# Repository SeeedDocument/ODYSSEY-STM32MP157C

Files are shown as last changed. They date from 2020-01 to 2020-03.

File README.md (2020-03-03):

---
name: ODYSSEY – STM32MP157C 
category: ODYSSEY
bzurl: https://www.seeedstudio.com/ODYSSEY-STM32MP157C-p-4464.html
wikiurl: http://wiki.seeedstudio.com/ODYSSEY-STM32MP157C/
sku: 102110319
---

# ODYSSEY – STM32MP157C

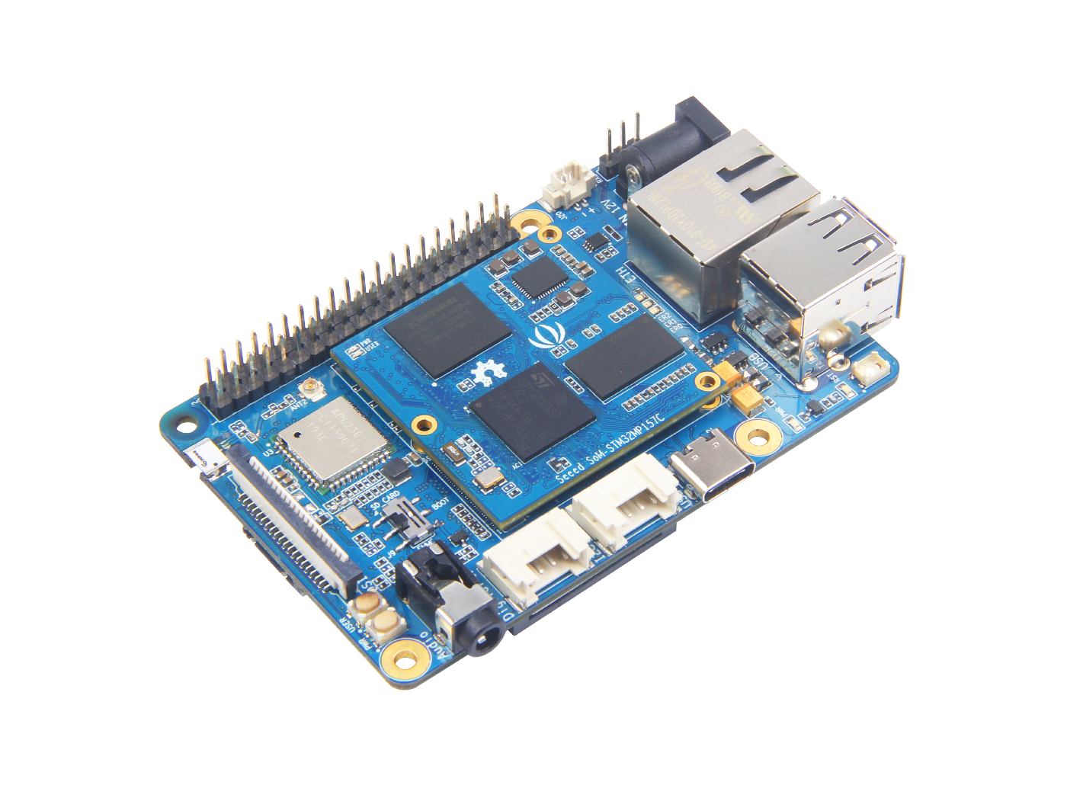
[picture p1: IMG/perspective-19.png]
 

The ODYSSEY – STM32MP157C is a single board computer that based on STM32MP157C, a dual-core Arm-Cortex-A7 core processor operating at 650Mhz. The processor also integrates an Arm Cortex-M4 coprocessor, which makes it suitable for real-time task. The ODYSSEY – STM32MP157C is created in a form of SoM(system on module) plus a Carrier board. The SoM has consisted of the MPU, PMIC, RAM and the carrier board is in Raspberry Pi form factor. The carries board includes all the necessary peripherals including Gigabytes Ethernet, WiFi/BLE, DC Power，USB Hosts, USB-C, MIPI-DSI, DVP for camera, audio, etc. With this board, customers can fast evaluate the SoM and deploy the SoM on their own carrier board easily and quickly.

Get one now (https://www.seeedstudio.com/ODYSSEY-STM32MP157C-p-4464.html)

## Features

- Dual-core Arm-Cortex-A7 core processor with Cortex-M4 integrated
- SoM(system on module) includes MPU, PMIC, RAM. 
- Raspberry Pi 40-Pin Compatible Carrier Board.
- Compact size and powerful
- open source hardware/SDK/API/BSP/OS

## Specification

|Item|Values|
|----|---|
|Peripheral Interface| 2 x USB Host<br>1 x gigabit Ethernet interface<br>1 x 3.5mm audio interface<br>1 x MIPI DSI display interface<br>1 x DVP camera interface<br>2 x Grove (GPIO & I2C)<br>1 x SD card interface (on the back of the board)|
|WiFi/Bluetooth|WiFi 802.11 b/g/n 2.4GHz<br>Bluetooth 4.1|
|On-board LED|1 x reset LED<br>3 x user-defined LED<br>1 x power LED|
|Power|1 x DC interface (12V/2A power input is recommended)<br>1 x USB Type - C|
|Button|1 x reset button<br>1 x user button<br>1 x dial code key|
|dimension|56mm x 85mm|
|Operating temperature | 0 ~ 75 ℃ |

## Application

- Industrial (CAN-Ethernet gateways etc )
- White goods(refrigerators,microwaves etc )
- Medical(data loggers etc)
- High-end wearables(VR device etc)
- Smart Home Devices

## Hardware Overview

<iframe src="https://3dwarehouse.sketchup.com/embed/6eecf961-5dd1-4baf-94e4-72f130c5542d" frameborder="0" scrolling="no" marginheight="0" marginwidth="0" width="580" height="326" allowfullscreen></iframe>

ODYSSEY – STM32MP157C consists of two parts: Carrier board and Seeed SoM - STM32MP157C.

Carrier board hardware details follow:

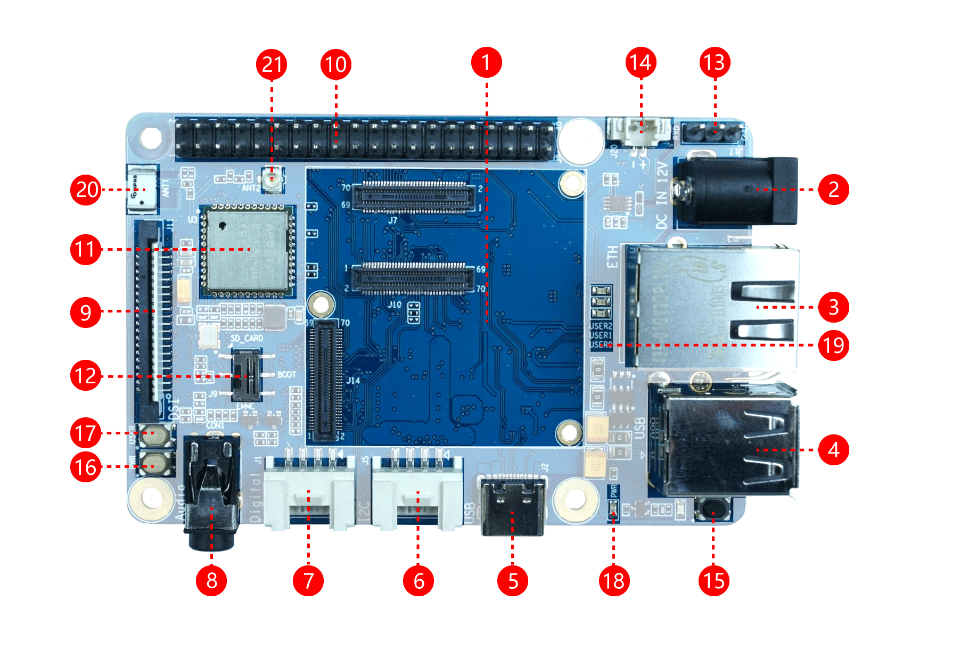
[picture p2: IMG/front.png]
 

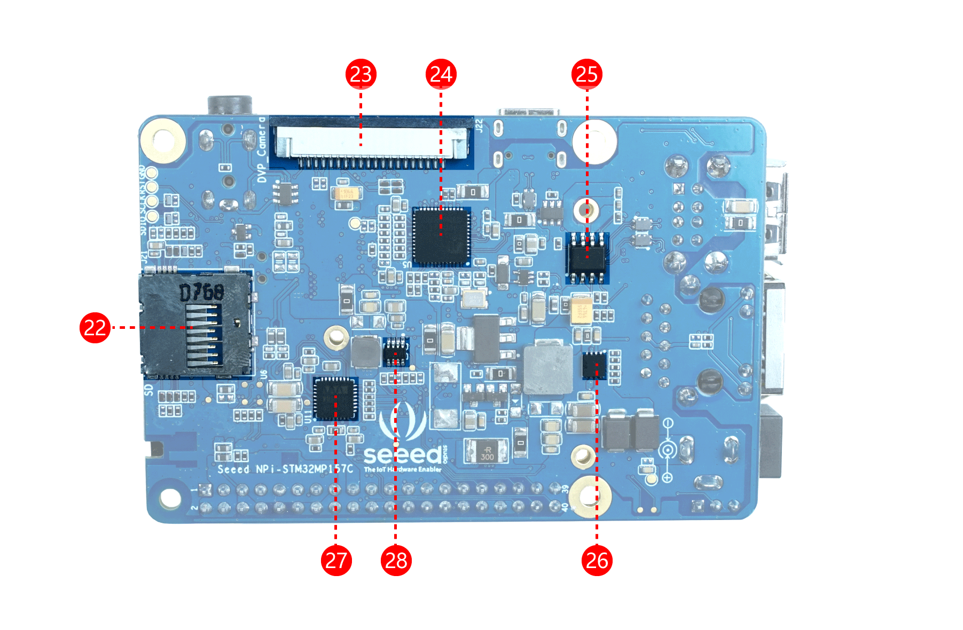
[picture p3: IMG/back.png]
 

- **1.Carrier board :** Install the Seeed SoM-STM32MP157C area, if the user wants to remove the core board, slowly tilt the core board up and then remove, never remove by hand.

- **2.DC Power Input Port :** 12V~24V/2A (12V/2A power input is recommended).

- **3.ETH Interface :** Network cable interface can be connected to gigabit level network.

- **4.USB Host:** Two USB Host ports.

- **5.USB Device:** USB 2.0 Type C. If Type C is used as board power input, a 5V/3A power adapter should be used.

- **6.Digital Grove Interface:** Connect the Grove interface to the digital pin. 

- **7.IIC Grove Interface:** Connect the Grove interface to the IIC pin.

- **8.American Standard 3.5mm:**  Audio interface.

- **9.MIPI DSI Interface:** Connect to a display with a MIPI DSI interface(FPC 20Pin 1.0mm).

- **10.40 PIN GPIO Interface:** Compatible with Raspberry Pi's 40-PIN.

- **11.AP6236:** 2.4G WiFi & BT 4.2 control chip.

- **12.Slide Switch:** Can be used to select SD card or eMMC to start.

- **13.Debug UART:** The system default debugging serial port can enter this serial port to access the system, we'll talk more about how to do that later.

- **14.JST 1.0mm:** 3VRTC battery interface.

- **15.RST Key:** system reset key.

- **16.PWR Button:** Long press about 8S to shut down, short press to boot.

- **17.User Button:** User programmable buttons.

- **18.PWR LED:** Development board power led.

- **19.User LED:** User programmable led.

- **20.ACA-5036-A2-CC-S:** Onboard 2.4G ceramic antenna.

- **21.The IPEX 1 generation:** External 2.4 G external antenna seat(When using an external antenna, need remove R49, R51 0Ω welding)

- **22. SD card slot:** Is the area where a micro-sd card with the system is inserted.

- **23.DVP camera interface :** Connect to camera with DVP interface (FPC 20Pin 1.0mm).

- **24.KSZ9031:** 1000M Network cable drive network card.

- **25.STMPS2252MTR:** Power switch chip.

- **26.MP9943:** Buck DCDC Power chip.

- **27.WM8960:** Audio codec chip.

- **28.MP2161:** Buck DCDC Power chip.

### Pin Function

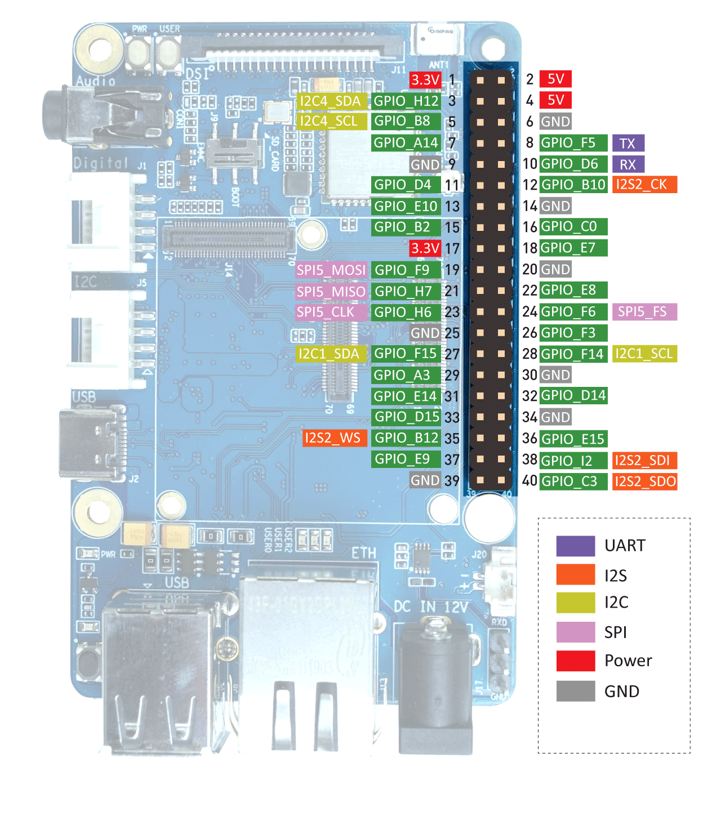
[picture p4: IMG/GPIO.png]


ODYSSEY - STM32MP157C's 40-pin is fully compatible with Raspberry Pi's 40PIN, including GPIO, IIC, UART, SPI, IIS and PWM pins.

## Introduction To Software

### Preparatory Work

**Materials Required**

- ODYSSEY – STM32MP157C
- Wi-Fi network
- 4GB (or more memory) SD card and SD card reader
- PC or Mac
- [USB To Uart Adapter](https://www.seeedstudio.com/USB-To-Uart-5V%26amp%3B3V3-p-1832.html) (optional)
- 12V/2A DC interface adapter for power supply (optional)
- A USB type-c cable

<div class="admonition warning">
<p class="admonition-title">Caution</p>
Please plug the USB cable gently, otherwise you may damage the interface.Please use the USB cable with 4 wires inside, the 2 wires cable can't transfer data. If you are not sure about the wire you have, you can click <a href="https://www.seeedstudio.com/USB-3-1-Type-C-to-A-Cable-1-Meter-3-1A-p-4085.html"><B>here</B></a> to buy
</div>

**Mirror Installation**

Like Raspberry Pi, you need to install the ODYSSEY – STM32MP157C image from your SD card to get it up and running. We offer two ways to start ODYSSEY – STM32MP157C. You can boot from an SD card or from eMMC.

**A. Boot from SD card**

- **Step 1.** Select the [firmware](https://github.com/Seeed-Studio/seeed-linux-images) you want to download:

- **Step 2.** Connect an SD card to a PC or MAC with an SD card reader, an SD card with more than 4G memory is required.

- **Step 3.** <font face="">Click here to download <a href="https://etcher.io/">Etcher</a>, then use the Etcher to write the  ```*.img.xz``` file directly to the SD card. Or extract the ```*.img.xz``` file into a ```*.img``` file, and then burn it to an SD card using another mirror write tool. 
<br>
<br>Click the plus icon to add the newly downloaded image file and the software will automatically select the SD card you inserted. Then click Flash! writing. It takes about 10 minutes to finish.</font>



- **Step 4.** After writing the image to the SD card, insert the SD card into ODYSSEY – STM32MP157C. Use USB type-c port to power the Carrier board. Do not take out the SD card during writing. ODYSSEY – STM32MP157C will boot from the SD card, you can see the PWR and USER LED lighting on SOM. Now, go to the next section: the serial console.

<div class="admonition note" >
<p class="admonition-title">Note</p>
they mean to start up failed if the USER LED does not blink.Please check the boot switch whether it is SD_CARD.
</div>

**B. Boot from eMMC card**

- **Step 1.** the process is the same as **A. Boot from SD card** if you first start up the ODYSSEY – STM32MP157C.

- **Step 2.** Edit /boot/uEnv.txt to start eMMC boot then reboot.

```bash
sudo echo cmdline=init=/opt/scripts/tools/eMMC/init-eMMC-flasher-v3-stm32mp1.sh >> /boot/uEnv.txt
sudo reboot
```

- **Step 3.** Wait for the USER LED bright continuously.that indicate the eMMC boot successfully if the USER LED bright continuously.

- **Step 4.** Power off and unplug the SD card.

- **Step 5.** Set the slide switch to EMMC and restart.

**Serial Console**

Now your ODYSSEY – STM32MP157C is up, you may want to access your Linux system through the console, then set up WiFi, and so on. Two serial port access methods are provided for Linux access: 

- A. OTG USB port - You need to run a Linux system on a circuit board.

- B. UART port - Used to debug low-level problems.

**A. Connect via OTG**

- **Step 1.** Take a USB type-c cable and make sure it's a data cable, plug it into ODYSSEY – STM32MP157C's USB type-c port, and then plug the other end of the USB type-c cable into your computer. 

- **Step 2.** Check whether the computer serial port is enabled:

    - Windows : Check the device manager, there should be a new serial device named ```COMx```, x is a bigger and bigger number. If you can not recognizes the driver you can visit [link](https://beagleboard.org/getting-started#troubleshooting) to install the driver.
    - Linux : ls ```/dev/ttyACM*```, should be ```/dev/ttyACMx``` x depends on the USB port you use.
    - Mac : ls ```/dev/cu.usb*```, should be ```/dev/cu.usbmodem14xx``` xx depends on the USB port you use.

- **Step 3.** Use your favorite serial debugging tool to connect to serial ports: 115200 baud rate, 8 bits, no parity bits, a stop bit 1, no flow control. Here are SoMe examples:

    - Windows : Use [PUTTY](https://www.chiark.greenend.org.uk/~sgtatham/putty/latest.html), select ```Serial``` protocol, fill in the COM port corresponding to ODYSSEY -STM32MP157C,```115200``` baud rate, 8 bit, no parity bits, a stop bit 1, no flow control.
    - Linux : Depending on the USB To TTL Adapter, should be ```screen /dev/ttyACM0(,1, and so on) 115200``` or ```screen /dev/ttyUSB0(,1, and so on) 115200```.
    - Mac : Depending on the USB To TTL Adapter, should be ```screen /dev/cu.usbserial1412(,1422, and so on) 115200``` or ```screen /dev/cu.usbmodem1412(,1422, and so on) 115200```.

- **Step 4.** The default user name is ```debian```, the password is ```temppwd```.

**B. Connect via UART port**

In this section, we'll walk you through the use of the USB to TTL adapter, which connects to the ODYSSEY – STM32MP157C's Uart port(Located at the upper right of ODYSSEY – STM32MP157C), to establish a connection between your computer and ODYSSEY -STM32MP157C.

- **Step 1.** Connect Uart port To PC/Mac using USB To TTL Adapter.If you don't have USB To TTL Adapter, click [HERE](https://www.seeedstudio.com/catalogsearch/result/?q=UART) to buy.（RX->TX,TX->RX）

- **Step 2.** Using the following serial debugging tools, the baud rate is 115200:
    - Windows : Use [PUTTY](https://www.chiark.greenend.org.uk/~sgtatham/putty/latest.html), select ```Serial``` protocol, fill in the COM port corresponding to ODYSSEY -STM32MP157C,```115200``` baud rate, 8 bit, no parity bits, a stop bit 1, no flow control.
    - Linux : Depending on the USB To TTL Adapter, should be ```screen /dev/ttyACM0(,1, and so on) 115200``` or ```screen /dev/ttyUSB0(,1, and so on) 115200```.
    - Mac : Depending on the USB To TTL Adapter, should be ```screen /dev/cu.usbserial1412(,1422, and so on) 115200``` or ```screen /dev/cu.usbmodem1412(,1422, and so on) 115200```.

- **Step 3.** The default user name is ```debian```, the password is ```temppwd```

- **Step 4.** If you don't have USB to TTL Adapter, you can also use Arduino. If you use Arduino, connect one end of the jumper to the Arduino's RESET pin and the other end to the Arduino's GND pin. This will bypass your Arduino's ATMEGA MCU and turn your Arduino into a USB to TTL adapter. Please refer [HERE](https://www.youtube.com/watch?v=qqSLwK1DP8Q) Video tutorial. Now connect the GND pin of Arduino to the GND pin of ODYSSEY -STM32MP157C's Uart port. Connect Rx pins on Arduino to Rx pins on ODYSSEY -STM32MP157C's Uart port. Connect the Tx pin on the Arduino to the Tx pin on the ODYSSEY -STM32MP157C Uart port. Finally, connect the Arduino to the PC/Mac via the Arduino's USB cable. Now check to see if your PC/Mac has found your Arduino by typing the following command:

```
ls /dev/cu.usb* (Mac)
ls /dev/ttyACM* (Linux)
```
You should get feedback like this:

```
/dev/cu.usbmodem14XX where XX will vary depending on which USB port you used (on Mac)
/dev/ttyACMX where X will vary depending on which USB port you used  (on Linux)
```
Now follow the steps above to connect to ODYSSEY – STM32MP157C via a serial connection. This is usually what we need to do when we first boot up, as you will then set up ODYSSEY – STM32MP157C for Wi-Fi connection and then SSH connection.

**Network Settings**

**A. Wi-Fi Settings**

Configure the ODYSSEY – STM32MP157C network through the network management tool `connmanctl`, which has been installed on the ODYSSEY -STM32MP157C image. Follow these instructions to easily complete the configuration. 

```
robot@ev3dev:~$ sudo connmanctl
Error getting VPN connections: The name net.connman.vpn was not provided by any
connmanctl> enable wifi
Enabled wifi
connmanctl> scan wifi
Scan completed for wifi
connmanctl> services
*AO Wired                ethernet_b827ebbde13c_cable
                         wifi_e8de27077de3_hidden_managed_none
    AH04044914           wifi_e8de27077de3_41483034303434393134_managed_psk
    Frissie              wifi_e8de27077de3_46726973736965_managed_psk
    ruijgt gast          wifi_e8de27077de3_7275696a67742067617374_managed_psk
    schuur               wifi_e8de27077de3_736368757572_managed_psk
connmanctl> agent on
Agent registered
connmanctl> connect wifi_e8de27077de3_41      # You can use the TAB key at this point to autocomplete the name
connmanctl> connect wifi_e8de27077de3_41483034303434393134_managed_psk
Agent RequestInput wifi_e8de27077de3_41483034303434393134_managed_psk
  Passphrase = [ Type=psk, Requirement=mandatory ]
Passphrase? *************
Connected wifi_e8de27077de3_41483034303434393134_managed_psk
connmanctl> quit
```

Now use the following command to find ODYSSEY – STM32MP157C's IP address. 
```
ifconfig
```

**B. Ethernet connection**

You can connect to the network using an Ethernet cable. Just plug in the Ethernet cable to the Internet.

**SSH connection**

**A. SSH**

SSH, short for Secure Shell, is formulated by the Network Working Group of IETF. SSH is a security protocol based on the application layer. SSH is a more reliable protocol that provides security for remote login sessions and other network services. There is no SSH protocol in the image provided by us, so we need to configure it through the serial port, so as to realize the communication between the device and the computer through SSH protocol. Enter the following command to install the SSH service in ODYSSEY -STM32MP157C.

```bash
sudo apt install ssh -y
```

Next, we'll use SSH to access ODYSSEY – STM32MP157C. Windows users can use third-party SSH clients. For Linux/Mac users, the SSH client is built in.

- Windows users : Use PUTTY, select SSH protocol, fill in the correct IP address and click open. The user name is debian and the password is temppwd.

- Linux/Mac users :
```
ssh debian@IP
// password: temppwd
```

<div class="admonition note" >
<p class="admonition-title">Note</p>
If the performance experience degrades while using SSH, please switch to a more accessible WiFi network.
</div>

## CANBUS Communication

The following is the process of CANBUS communication using [2 Channel CAN BUS FD Shield for Raspberry Pi](https://www.seeedstudio.com/2-Channel-CAN-BUS-FD-Shield-for-Raspberry-Pi-p-4072.html) based on ODYSSEY -- STM32MP157C, first use [Seeeduino V4.2](https://www.seeedstudio.com/Seeeduino-V4-2-p-2517.html) to collect the environment temperature and humidity, and then through the Seeeduino V4.2 [CAN - BUS shields V2](https://www.seeedstudio.com/CAN-BUS-Shield-V2.html) above and the ODYSSEY – STM32MP157C Channel 2 CAN BUS FD shields above for Raspberry Pi communication.

###Preparation Work

**Materials Required**

- ODYSSEY - STM32MP157C
- Wi-Fi network
- 4GB (or more than 4GB) SD card and SD card reader
- PC or Mac
- [USB To Uart Adapter](https://www.seeedstudio.com/USB-To-Uart-5V%26amp%3B3V3-p-1832.html)(optional)
- 12V/2ADC interface adapter for power supply (optional)
- A USB type-c cable
- Two double-male dupont lines
- [CAN-BUS Shield V2](https://www.seeedstudio.com/CAN-BUS-Shield-V2.html)
- [Seeeduino V4.2](https://www.seeedstudio.com/Seeeduino-V4-2-p-2517.html)
- [2 Channel CAN BUS FD Shield for Raspberry Pi](https://www.seeedstudio.com/2-Channel-CAN-BUS-FD-Shield-for-Raspberry-Pi-p-4072.html)
- [Grove - Light Sensor v1.2](https://www.seeedstudio.com/Grove-Light-Sensor-v1-2.html)
- [Grove - I2C High Accuracy Temp&Humi Sensor (SHT35)](https://www.seeedstudio.com/catalogsearch/result/?q=sht35)

**Hardware Connection**

- **Step 1.** According to the [installation guide](http://wiki.seeedstudio.com/2-Channel-CAN-BUS-FD-Shield-for-Raspberry-Pi/#mounting-guide) insert 2 Channel CAN BUS FD Shield for Raspberry Pi onto ODYSSEY - STM32MP157C.
- **Step 2.** Insert CAN BUS Shield V2 into Seeeduino V4.2.
- **Step 3.** Connect Channel CAN BUS FD Shield for Raspberry Pi to can-bus Shield V2 using dupont wire.

|2 Channel CAN BUS FD Shield for Raspberry Pi|CAN-BUS Shield V2|
|:----:|:---:|
|CAN_0_L|CANL|
|CAN_0_H|CANH|

- **Step 4.** Power ODYSSEY STM32MP157C and Seeeduino V4.2

**Dependency installation**

- **Step 1.** Install the environment for `python`.

```bsah
sudo apt update
sudo apt install python3 python3-distutils python3-pyqt5  python3-pip python3-numpy -y
sudo pip3 install python-can pyqtgraph
```
- **Step 2.** Install `git`.

```bsah
sudo apt install git -y
```

- **Step 3.** Install the `make` related environment.

```bsah
sudo apt install make device-tree-compiler gcc -y
```

### software installation

**Install CAN-HAT and LCD drivers**

- **Step 1.** Check the version of Linux kernel in the current environment and install the header file of kernel version.

```bash
dpkg -l | grep linux
sudo apt install linux-headers-$(uname -r) -y
```

- **Step 2.** Make and install driver of stm32p1 from `seeed-linux-dtverlays` in the GitHub.

```bash
git clone https://github.com/Seeed-Studio/seeed-linux-dtverlays
cd seeed-linux-dtverlays
make all_stm32mp1 && sudo make install_stm32mp1
```

- **Step 3.** add dtbo package in `/boot/uEnv.txt` to make it become effective after reboot.

```bash
sudo echo uboot_overlay_addr0=/lib/firmware/stm32mp1-seeed-lcd-01-overlay.dtbo >> /boot/uEnv.txt
sudo echo uboot_overlay_addr1=/lib/firmware/stm32mp1-MCP2517FD-can0-overlay.dtbo >> /boot/uEnv.txt
sudo reboot
```

- **Step 4.** Check the driver whether install successfully by using `dmesg`, you will view the below information if it is successful.

```bash
debian@npi:~$ sudo insmod /lib/modules/$(uname -r)/extra/seeed/mcp25xxfd-can.ko
debian@npi:~$ dmesg | grep spi
[    1.057609] spi_stm32 44009000.spi: driver initialized
[    9.852726] mcp25xxfd spi0.0: Linked as a consumer to regulator.6
[    9.966510] mcp25xxfd spi0.0: MCP2517 successfully initialized.

debian@npi:~$ ifconfig -a
can0: flags=128<NOARP>  mtu 16
        unspec 00-00-00-00-00-00-00-00-00-00-00-00-00-00-00-00  txqueuelen 10  (UNSPEC)
        RX packets 0  bytes 0 (0.0 B)
        RX errors 0  dropped 0  overruns 0  frame 0
        TX packets 0  bytes 0 (0.0 B)
        TX errors 0  dropped 0 overruns 0  carrier 0  collisions 0
```

**Config CAN-HAT and LCD**

- **Step 1.** Configure `can-bus`

```bash
sudo ip link set can0 up type can bitrate 500000 dbitrate 8000000 restart-ms 1000 berr-reporting on fd on
sudo ifconfig can0 txqueuelen 65536

debian@npi:~$ ip -details link show can0
3: can0: <NOARP,UP,LOWER_UP,ECHO> mtu 16 qdisc pfifo_fast state UNKNOWN mode DEFAULT group default qlen 10
    link/can  promiscuity 0 minmtu 0 maxmtu 0
    can state ERROR-ACTIVE (berr-counter tx 0 rx 0) restart-ms 0
          bitrate 500000 sample-point 0.875
          tq 25 prop-seg 34 phase-seg1 35 phase-seg2 10 sjw 1
          mcp25xxfd: tseg1 2..256 tseg2 1..128 sjw 1..128 brp 1..256 brp-inc 1
          mcp25xxfd: dtseg1 1..32 dtseg2 1..16 dsjw 1..16 dbrp 1..256 dbrp-inc 1
          clock 40000000numtxqueues 1 numrxqueues 1 gso_max_size 65536 /gso_max_segs 65535
```

- **Step 2.** Configure the `lcd` environment

```bash
export QT_QPA_PLATFORM=linuxfb:fb=/dev/fb0
```

### Run the Demo

Run the following code on 'ODYSSEY - STM32MP157C'

```bash
cd ~
git clone https://github.com/SeeedDocument/ODYSSEY-STM32MP157C.git
cd ~/ODYSSEY-STM32MP157C/examples
python3 QtViewerForStm32p1.py
```

Run [CanBus_SendForArduino.ino](https://github.com/SeeedDocument/ODYSSEY-STM32MP157C/blob/master/examples/CanBus_SendForArduino.ino) on `Seeeduino V4.2`.

## Resourses
-----
- **[PDF]** [STM32MP157C Datasheet](https://github.com/SeeedDocument/ODYSSEY-STM32MP157C/raw/master/Hardware/STM32MP157C.pdf)
- **[SCH]** [Seeed SoM - STM32MP157C](https://github.com/SeeedDocument/ODYSSEY-STM32MP157C/raw/master/Hardware/Seeed%20SoM%20-%20STM32MP157C%20v1.0_191212.pdf)
- **[SCH]** [ODYSSEY-STM32MP157C](https://github.com/SeeedDocument/ODYSSEY-STM32MP157C/raw/master/Hardware/Seeed%20NPi%20-%20STM32MP157C%20v1.0_191212.pdf)
- **[3Dfile]** [ODYSSEY-STM32MP157C](https://github.com/SeeedDocument/ODYSSEY-STM32MP157C/raw/master/Hardware/st.skp)

## Tech Support
Please submit any technical issue into our [forum](http://forum.seeedstudio.com/). <br /><p style="text-align:center"></p>

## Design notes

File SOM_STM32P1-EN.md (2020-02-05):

# SOM – STM32MP157C 

SOM - STM32MP157C is the SOM based on STM32MP157C, STM32MP157C is a dual-core arm-cortex-a7 core processor operating at 650Mhz, the processor is also integrated with the Arm cortex-m4 coprocessor, Arm cortex-m4 integrates FPU and MPU. Cortex-a7 mainly does things at the operating system level, Cortex-m handles things at the MCU level. It can reach the optimal state at any time, making it suitable for various application scenarios.

<p style=":center"></p>

## Features

- Compact in size and powerful in function
- Scalable industrial grade products
- Open Source Hardware/ SDK / API / BSP / OS

## Application

- Consumer
- Industrial
- White goods
- Medical
- High quality wearable devices

## Specification

|Item|Value|
|----|---|
|MPU(STM32MP157C)|1 x 32-bit dual-core Arm Cortex-A7 <br>1 x 32-bit Arm Cortex-M4 with FPU/MPU|
|PMU|1 x ST PMIC STPMIC1A |
|RAM|1 x 512MB DDR3 RAM|
|Flash|1 x 4GB EMMC|
|Peripheral Interface|3 x board-to-board 70-Pin connector|
|dimension|38mm x 38mm|

## Hardware 

Here are the hardware details for Seeed SoM - STM32MP157C:

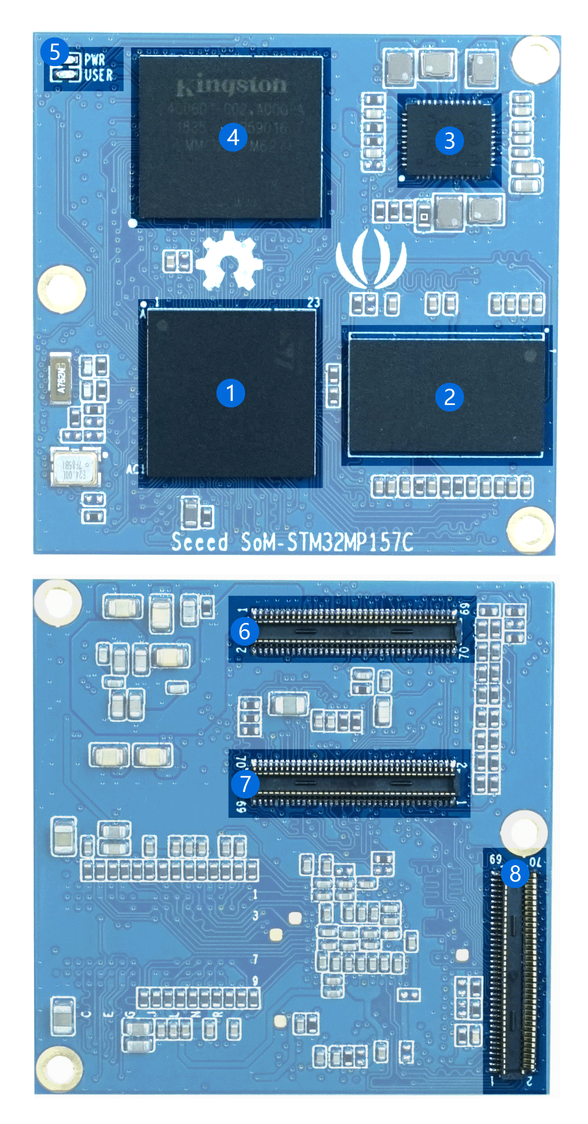
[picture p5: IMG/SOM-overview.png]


- **1.STM32MP157C:** Development board main control chip(Dual architecture processor: Arm® Cortex®-A7 and Cortex®-M4 )

- **2.MT41K256M16TW-107:P:** 512M16bitRAM Memory Chip

- **3.STPMIC1APQR:** Power Management Chip

- **4.EMMC04G-M627:** 4GeMMC Memory

- **5.LED:** When the power supply is successful, the PWR will go on. When the system is running normally, the USER will keep flashing.

- **6.70-PIN connector:** You can find the function for each pin from the table below:

|Pin Package Number|Pin Number|Pin Name|Pin Type|Optional Function|Additional Function|
|:---:|:---:|:---:|:---:|:---:|:---:|
|-|1|5V_VIN|S|-|-|
|-|2|3V3|S|-|-|
|-|3|5V_VIN|S|-|-|
|-|4|3V3|S|-|-|
|-|5|5V_VIN|S|-|-|
|-|6|3V3|S|-|-|
|-|7|5V_VIN|S|-|-|
|-|8|3V3|S|-|-|
|-|9|5V_VIN|S|-|-|
|-|10|3V3|S|-|-|
|-|11|5V_VIN|S|-|-|
|-|12|VDD|S|-|-|
|-|13|5V_VIN|S|-|-|
|-|14|VDD|S|-|-|
|-|15|5V_VIN|S|-|-|
|-|16|VBUS_OTG|S|-|-|
|-|17|BST_OUT|S|-|-|
|-|18|VBUS_OTG|S|-|-|
|-|19|BST_OUT|S|-|-|
|-|20|VBUS_SW|S|-|-|
|-|21|BST_OUT|S|-|-|
|-|22|VBUS_SW|S|-|-|
|-|23|1V8_AUDIO|S|-|-|
|-|24|VBUS_SW|S|-|-|
|-|25|1V2_HDMI|S|-|-|
|-|26|VBAT|S|-|-|
|-|27|3V3_HDMI|S|-|-|
|-|28|VBAT|S|-|-|
|-|29|-|-|-|-|
|-|30|-|-|-|-|
|R4|31|VREF+|S|-|-|
|AC4|32|PF14|I/O|TRACED6, DFSDM1_CKIN6,I2C4_SCL, I2C1_SCL,ETH1_GMII_RXD6, FMC_A8,EVENTOUT|ADC2_INP6,ADC2_INN2|
|Y5|33|PF13|I/O|TRACED5, DFSDM1_DATIN6,I2C4_SMBA, I2C1_SMBA,DFSDM1_DATIN3,ETH1_GMII_RXD5, FMC_A7,EVENTOUT|ADC2_INP2|
|Y4|34|PF15|I/O|TRACED7, I2C4_SDA,I2C1_SDA, ETH1_GMII_RXD7,FMC_A9, EVENTOUT|-|
|-|35|GND|S|-|-|
|L3|36|PD14|I/O|TIM4_CH3, SAI3_MCLK_B,UART8_CTS,FMC_AD0/FMC_D0,EVENTOUT|-|
|U3|37|ANA0|A|-|ADC1_INP0,ADC1_INN1,ADC2_INP0,ADC2_INN1|
|J2|38|PD15|I/O|TIM4_CH4, SAI3_MCLK_A,UART8_CTS,FMC_AD1/FMC_D1,LCD_R1,EVENTOUT|-|
|U4|39|ANA1|A|-|ADC1_INP1,ADC2_INP1|
|R2|40|PWR_ON|O|-|PWR_ONLP|
|-|41|-|-|-|-|
|-|42|GND|S|-|-|
|-|43|-|-|-|-|
|-|44|PA14|I/O|DBTRGO, DBTRGI, MCO2, EVENTOUT|-|
|-|45|PONKEYN|I|-|-|
|-|46|-|-|-|-|
|-|47|-|-|-|-|
|-|48|-|-|-|-|
|-|49|-|-|-|-|
|-|50|-|-|-|-|
|-|51|-|-|-|-|
|-|52|-|-|-|-|
|-|53|-|-|-|-|
|-|54|-|-|-|-|
|-|55|-|-|-|-|
|-|56|-|-|-|-|
|-|57|-|-|-|-|
|-|58|-|-|-|-|
|-|59|-|-|-|-|
|-|60|-|-|-|-|
|-|61|-|-|-|-|
|-|62|-|-|-|-|
|-|63|-|-|-|-|
|-|64|-|-|-|-|
|-|65|-|-|-|-|
|-|66|-|-|-|-|
|-|67|-|-|-|-|
|-|68|-|-|-|-|
|-|69|-|-|-|-|
|-|70|-|-|-|-|

- **7.70-PIN connector:** You can find the function for each pin from the table below:

|Pin Package Number|Pin Number|Pin Name|Pin Type|Optional Function|Additional Function|
|:---:|:---:|:---:|:---:|:---:|:---:|
|-|1|5V_VIN|S|-|-|
|-|2|3V3|S|-|-|
|-|3|5V_VIN|S|-|-|
|-|4|3V3|S|-|-|
|-|5|5V_VIN|S|-|-|
|-|6|3V3|S|-|-|
|-|7|5V_VIN|S|-|-|
|-|8|3V3|S|-|-|
|-|9|5V_VIN|S|-|-|
|-|10|3V3|S|-|-|
|-|11|5V_VIN|S|-|-|
|-|12|VDD|S|-|-|
|-|13|5V_VIN|S|-|-|
|-|14|VDD|S|-|-|
|-|15|5V_VIN|S|-|-|
|-|16|VBUS_OTG|S|-|-|
|-|17|BST_OUT|S|-|-|
|-|18|VBUS_OTG|S|-|-|
|-|19|BST_OUT|S|-|-|
|-|20|VBUS_SW|S|-|-|
|-|21|BST_OUT|S|-|-|
|-|22|VBUS_SW|S|-|-|
|-|23|1V8_AUDIO|S|-|-|
|-|24|VBUS_SW|S|-|-|
|-|25|1V2_HDMI|S|-|-|
|-|26|VBAT|S|-|-|
|-|27|3V3_HDMI|S|-|-|
|-|28|VBAT|S|-|-|
|-|29|-|-|-|-|
|-|30|-|-|-|-|
|R4|31|VREF+|S|-|-|
|AC4|32|PF14|I/O|TRACED6, DFSDM1_CKIN6,I2C4_SCL, I2C1_SCL,ETH1_GMII_RXD6, FMC_A8,EVENTOUT|ADC2_INP6,ADC2_INN2|
|Y5|33|PF13|I/O|TRACED5, DFSDM1_DATIN6,I2C4_SMBA, I2C1_SMBA,DFSDM1_DATIN3,ETH1_GMII_RXD5, FMC_A7,EVENTOUT|ADC2_INP2|
|Y4|34|PF15|I/O|TRACED7, I2C4_SDA,I2C1_SDA, ETH1_GMII_RXD7,FMC_A9, EVENTOUT|-|
|-|35|GND|S|-|-|
|L3|36|PD14|I/O|TIM4_CH3, SAI3_MCLK_B,UART8_CTS,FMC_AD0/FMC_D0,EVENTOUT|-|
|U3|37|ANA0|A|-|ADC1_INP0,ADC1_INN1,ADC2_INP0,ADC2_INN1|
|J2|38|PD15|I/O|TIM4_CH4, SAI3_MCLK_A,UART8_CTS,FMC_AD1/FMC_D1,LCD_R1,EVENTOUT|-|
|U4|39|ANA1|A|-|ADC1_INP1,ADC2_INP1|
|R2|40|PWR_ON|O|-|PWR_ONLP|
|-|41|-|-|-|-|
|-|42|GND|S|-|-|
|-|43|-|-|-|-|
|-|44|PA14|I/O|DBTRGO, DBTRGI, MCO2, EVENTOUT|-|
|-|45|PONKEYN|I|-|-|
|-|46|-|-|-|-|
|-|47|-|-|-|-|
|-|48|-|-|-|-|
|-|49|-|-|-|-|
|-|50|-|-|-|-|
|-|51|-|-|-|-|
|-|52|-|-|-|-|
|-|53|-|-|-|-|
|-|54|-|-|-|-|
|-|55|-|-|-|-|
|-|56|-|-|-|-|
|-|57|-|-|-|-|
|-|58|-|-|-|-|
|-|59|-|-|-|-|
|-|60|-|-|-|-|
|-|61|-|-|-|-|
|-|62|-|-|-|-|
|-|63|-|-|-|-|
|-|64|-|-|-|-|
|-|65|-|-|-|-|
|-|66|-|-|-|-|
|-|67|-|-|-|-|
|-|68|-|-|-|-|
|-|69|-|-|-|-|
|-|70|-|-|-|-|

- **8.70-PIN connector:** You can find the function for each pin from the table below:

|Pin Package Number|Pin Number|Pin Name|Pin Type|Optional Function|Additional Function|
|:---:|:---:|:---:|:---:|:---:|:---:|
|-|1|5V_VIN|S|-|-|
|-|2|3V3|S|-|-|
|-|3|5V_VIN|S|-|-|
|-|4|3V3|S|-|-|
|-|5|5V_VIN|S|-|-|
|-|6|3V3|S|-|-|
|-|7|5V_VIN|S|-|-|
|-|8|3V3|S|-|-|
|-|9|5V_VIN|S|-|-|
|-|10|3V3|S|-|-|
|-|11|5V_VIN|S|-|-|
|-|12|VDD|S|-|-|
|-|13|5V_VIN|S|-|-|
|-|14|VDD|S|-|-|
|-|15|5V_VIN|S|-|-|
|-|16|VBUS_OTG|S|-|-|
|-|17|BST_OUT|S|-|-|
|-|18|VBUS_OTG|S|-|-|
|-|19|BST_OUT|S|-|-|
|-|20|VBUS_SW|S|-|-|
|-|21|BST_OUT|S|-|-|
|-|22|VBUS_SW|S|-|-|
|-|23|1V8_AUDIO|S|-|-|
|-|24|VBUS_SW|S|-|-|
|-|25|1V2_HDMI|S|-|-|
|-|26|VBAT|S|-|-|
|-|27|3V3_HDMI|S|-|-|
|-|28|VBAT|S|-|-|
|-|29|-|-|-|-|
|-|30|-|-|-|-|
|R4|31|VREF+|S|-|-|
|AC4|32|PF14|I/O|TRACED6, DFSDM1_CKIN6,I2C4_SCL, I2C1_SCL,ETH1_GMII_RXD6, FMC_A8,EVENTOUT|ADC2_INP6,ADC2_INN2|
|Y5|33|PF13|I/O|TRACED5, DFSDM1_DATIN6,I2C4_SMBA, I2C1_SMBA,DFSDM1_DATIN3,ETH1_GMII_RXD5, FMC_A7,EVENTOUT|ADC2_INP2|
|Y4|34|PF15|I/O|TRACED7, I2C4_SDA,I2C1_SDA, ETH1_GMII_RXD7,FMC_A9, EVENTOUT|-|
|-|35|GND|S|-|-|
|L3|36|PD14|I/O|TIM4_CH3, SAI3_MCLK_B,UART8_CTS,FMC_AD0/FMC_D0,EVENTOUT|-|
|U3|37|ANA0|A|-|ADC1_INP0,ADC1_INN1,ADC2_INP0,ADC2_INN1|
|J2|38|PD15|I/O|TIM4_CH4, SAI3_MCLK_A,UART8_CTS,FMC_AD1/FMC_D1,LCD_R1,EVENTOUT|-|
|U4|39|ANA1|A|-|ADC1_INP1,ADC2_INP1|
|R2|40|PWR_ON|O|-|PWR_ONLP|
|-|41|-|-|-|-|
|-|42|GND|S|-|-|
|-|43|-|-|-|-|
|-|44|PA14|I/O|DBTRGO, DBTRGI, MCO2, EVENTOUT|-|
|-|45|PONKEYN|I|-|-|
|-|46|-|-|-|-|
|-|47|-|-|-|-|
|-|48|-|-|-|-|
|-|49|-|-|-|-|
|-|50|-|-|-|-|
|-|51|-|-|-|-|
|-|52|-|-|-|-|
|-|53|-|-|-|-|
|-|54|-|-|-|-|
|-|55|-|-|-|-|
|-|56|-|-|-|-|
|-|57|-|-|-|-|
|-|58|-|-|-|-|
|-|59|-|-|-|-|
|-|60|-|-|-|-|
|-|61|-|-|-|-|
|-|62|-|-|-|-|
|-|63|-|-|-|-|
|-|64|-|-|-|-|
|-|65|-|-|-|-|
|-|66|-|-|-|-|
|-|67|-|-|-|-|
|-|68|-|-|-|-|
|-|69|-|-|-|-|
|-|70|-|-|-|-|

## Resourses
-----
- **[PDF]** [STM32MP157C Datasheet](https://github.com/SeeedDocument/Seeed-NPi-STM32MP157C/raw/master/Hardware/stm32mp157c.pdf)
- **[SCH]** [Seeed STM32MP157C SOM](https://github.com/SeeedDocument/Seeed-NPi-STM32MP157C/raw/master/Hardware/Seeed%20SoM%20-%20STM32MP157C%20v1.0_191212.pdf)
- **[SCH]** [Seeed STM32MP157C NPi](https://github.com/SeeedDocument/Seeed-NPi-STM32MP157C/raw/master/Hardware/Seeed%20NPi%20-%20STM32MP157C%20v1.0_191212.pdf)

## Tech Support
Please submit any technical issue into our [forum](http://forum.seeedstudio.com/). <br /><p style="text-align:center"></p>

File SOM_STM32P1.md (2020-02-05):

# SOM – STM32MP157C 

SOM – STM32MP157C是基于STM32MP157C的SOM，STM32MP157C是工作在650Mhz的双核Arm-Cortex-A7核心处理器，该处理器还集成了Arm Cortex-M4协处理器，其中Arm Cortex-M4里面集成了FPU和MPU，Cortex-A7主要做操作系统级别的事情而Cortex-M则负责处理MCU级别的事情，任何时候都能达到最佳的状态，使其适用于各种应用场景.

 (https://item.taobao.com/item.htm?spm=a1z10.3-c.w4002-11172317909.10.1e729b66GJVV3r&id=533937368398)

## 产品特性

- 体积小巧,功能强大
- 可扩展的工业级
- 开源硬件/ SDK / API / BSP / OS

## 创意应用

- 消费者
- 工业
- 白色家电
- 医疗
- 高端可穿戴设备

## 规格参数

|项目|参数值|
|----|---|
|MPU(STM32MP157C)|1 x 32-bit dual-core Arm Cortex-A7 <br>1 x 32-bit Arm Cortex-M4 with FPU/MPU|
|PMU|1 x ST PMIC STPMIC1A |
|RAM|1 x 512MB DDR3 RAM|
|Flash|1 x 4GB EMMC|
|外围接口|3 x 板对板70-Pin连接器|
|尺寸|38mm x 38mm|

## 硬件概述

下面是Seeed SOM - STM32MP157C的硬件详细说明



- **1.STM32MP157C:** 开发板的主控制芯片(Arm® Cortex®-A7 和 Cortex®-M4双架构处理器)

- **2.MT41K256M16TW-107:P:** 512M16bitRAM内存芯片

- **3.STPMIC1APQR:** 电源管理芯片

- **4.EMMC04G-M627:** 4GeMMC内存

- **5.LED:** 当供电成功时,PWR会被点亮,当系统正常运行时,USER将会无限循环闪烁.

- **6.70-PIN接口:** 可以从下面的表格来查找每个引脚对应的功能

|Pin 封装编号|Pin 编号|Pin 名称|Pin 类型|可选择的功能|附加功能|
|:---:|:---:|:---:|:---:|:---:|:---:|
|-|1|5V_VIN|S|-|-|
|-|2|3V3|S|-|-|
|-|3|5V_VIN|S|-|-|
|-|4|3V3|S|-|-|
|-|5|5V_VIN|S|-|-|
|-|6|3V3|S|-|-|
|-|7|5V_VIN|S|-|-|
|-|8|3V3|S|-|-|
|-|9|5V_VIN|S|-|-|
|-|10|3V3|S|-|-|
|-|11|5V_VIN|S|-|-|
|-|12|VDD|S|-|-|
|-|13|5V_VIN|S|-|-|
|-|14|VDD|S|-|-|
|-|15|5V_VIN|S|-|-|
|-|16|VBUS_OTG|S|-|-|
|-|17|BST_OUT|S|-|-|
|-|18|VBUS_OTG|S|-|-|
|-|19|BST_OUT|S|-|-|
|-|20|VBUS_SW|S|-|-|
|-|21|BST_OUT|S|-|-|
|-|22|VBUS_SW|S|-|-|
|-|23|1V8_AUDIO|S|-|-|
|-|24|VBUS_SW|S|-|-|
|-|25|1V2_HDMI|S|-|-|
|-|26|VBAT|S|-|-|
|-|27|3V3_HDMI|S|-|-|
|-|28|VBAT|S|-|-|
|-|29|-|-|-|-|
|-|30|-|-|-|-|
|R4|31|VREF+|S|-|-|
|AC4|32|PF14|I/O|TRACED6,DFSDM1_CKIN6,I2C4_SCL,I2C1_SCL,ETH1_GMII_RXD6,FMC_A8,EVENTOUT|ADC2_INP6,ADC2_INN2|
|Y5|33|PF13|I/O|TRACED5,DFSDM1_DATIN6,I2C4_SMBA,I2C1_SMBA,DFSDM1_DATIN3,ETH1_GMII_RXD5,FMC_A7,EVENTOUT|ADC2_INP2|
|Y4|34|PF15|I/O|TRACED7,I2C4_SDA,I2C1_SDA, ETH1_GMII_RXD7,FMC_A9, EVENTOUT|-|
|-|35|GND|S|-|-|
|L3|36|PD14|I/O|TIM4_CH3,SAI3_MCLK_B,UART8_CTS,FMC_AD0/FMC_D0,EVENTOUT|-|
|U3|37|ANA0|A|-|ADC1_INP0,ADC1_INN1,ADC2_INP0,ADC2_INN1|
|J2|38|PD15|I/O|TIM4_CH4,SAI3_MCLK_A,UART8_CTS,FMC_AD1/FMC_D1,LCD_R1,EVENTOUT|-|
|U4|39|ANA1|A|-|ADC1_INP1,ADC2_INP1|
|R2|40|PWR_ON|O|-|PWR_ONLP|
|-|41|GND|S|-|-|
|K2|42|PC13|I/O|EVENTOUT|RTC_OUT1/RTC_TS/RTC_LSCO,TAMP_IN1/TAMP_OUT2/TAMP_OUT3,WKUP3|
|T2|43|PA14|I/O|DBTRGO,DBTRGI,MCO2,EVENTOUT|-|
|AB3|44|PA0|I/O|TIM2_CH1/TIM2_ETR,TIM5_CH1,TIM8_ETR,TIM15_BKIN,USART2_CTS/USART2_NSS,UART4_TX,SDMMC2_CMD,SAI2_SD_B,ETH1_GMII_CRS/ETH1_MII_CRS,EVENTOUT|ADC1_INP16,WKUP1|
|G2|45|PZ4|I/O|I2C6_SCL,I2C2_SCL,I2C5_SCL,I2C4_SCL,EVENTOUT|-|
|-|46|PONKEYN|S|-|-|
|B6|47|PD4|I/O|SAI3_FS_A,USART2_RTS/USART2_DE,SDMMC3_D1,DFSDM1_CKIN0,FMC_NOE,EVENTOUT|-|
|-|48|GDN|S|-|-|
|Y9|49|PF12|I/O|TRACED4,ETH1_GMII_RXD4,FMC_A6,EVENTOUT|ADC1_INP6,ADC1_INN2|
|M3|50|NRST|I/O|-|-|
|AC11|51|PF8|I/O|TRACED12,TIM16_CH1N,SPI5_MISO,SAI1_SCK_B,UART7_RTS/UART7_DE,TIM13_CH1,QUADSPI_BK1_IO0,EVENTOUT|-|
|C20|52|JTMS-SWDIO|I/O|-|-|
|U1|53|PF3|I/O|ETH1_GMII_TX_ER,FMC_A3,EVENTOUT|-|
|B20|54|JTCK-SWCLK|I|-|-|
|Y7|55|PG11|I/O|TRACED11,USART1_TX,UART4_TX,SPDIFRX_IN0,ETH1_GMII_TX_EN/ETH1_MII_TX_EN/ETH1_RGMII_TX_CTL/ETH1_RMII_TX_EN,DCMI_D3,LCD_B3,EVENTOUT|-|
|A20|56|JTDI|I|-|-|
|-|57|GND|S|-|-|
|A19|58|JTDO-TRACESWO|O|-|-|
|-|59|GND|S|-|-|
|B19|60|NJTRST|I|-|-|
|AB17|61|USB_DM1|A|-|USBH_HS_DM1|
|-|62|GND|S|-|-|
|AC17|63|USB_DP1|A|-|USBH_HS_DP1|
|Y8|64|PB5|I/O|ETH_CLK,TIM17_BKIN,TIM3_CH2,SAI4_D1,I2C1_SMBA,SPI1_MOSI/I2S1_SDO,I2C4_SMBA,SPI3_MOSI/I2S3_SDO,SPI6_MOSI,FDCAN2_RX,SAI4_SD_A,ETH1_PPS_OUT,UART5_RX,DCMI_D10,LCD_G7,EVENTOUT|-|
|-|65|GND|S|-|-|
|AA10|66|PB13|I/O|TIM1_CH1N,DFSDM1_CKOUT,LPTIM2_OUT,SPI2_SCK/I2S2_CK,DFSDM1_CKIN1,USART3_CTS/USART3_NSS,FDCAN2_TX,ETH1_GMII_TXD1/ETH1_MII_TXD1/ETH1_RGMII_TXD1/ETH1_RMII_TXD1,UART5_TX,EVENTOUT|-|
|AB16|67|USB_DM2|A|-|USBH_HS_DM2,OTG_HS_DM|
|B8|68|PD0|I/O|I2C6_SDA,DFSDM1_CKIN6,I2C5_SDA,SAI3_SCK_A,UART4_RX,FDCAN1_RX,SDMMC3_CMD,DFSDM1_DATIN7,FMC_AD2/FMC_D2,EVENTOUT|-|
|AC16|69|USB_DP2|A|-|USBH_HS_DP2,OTG_HS_DP|
|B9|70|PD1|I/O|I2C6_SCL,DFSDM1_DATIN6,I2C5_SCL,SAI3_SD_A,UART4_TX,FDCAN1_TX,SDMMC3_D0,DFSDM1_CKIN7,FMC_AD3/FMC_D3,EVENTOUT|-|

- **7.70-PIN接口:** 可以从下面的表格来查找每个引脚对应的功能

|Pin 封装编号|Pin 编号|Pin 名称|Pin 类型|可选择的功能|附加功能|
|:---:|:---:|:---:|:---:|:---:|:---:|
|D2|1|PD6|I/O|TIM16_CH1N,SAI1_D1,DFSDM1_CKIN4,DFSDM1_DATIN1,SPI3_MOSI/I2S3_SDO,SAI1_SD_A,USART2_RX,FMC_NWAIT,DCMI_D10,LCD_B2,EVENTOUT|-|
|AB19|2|PA12|I/O|TIM1_ETR,I2C6_SDA,I2C5_SDA,UART4_TX,USART1_RTS/USART1_DE,SAI2_FS_B,FDCAN1_TX,LCD_R5,EVENTOUT|OTG_FS_DP|
|D7|3|PF5|I/O|USART2_TX,SDMMC3_D2,FMC_A5,EVENTOUT|-|
|AA18|4|PA11|I/O|TIM1_CH4,I2C6_SCL,I2C5_SCL,SPI2_NSS/I2S2_WS,UART4_RX,USART1_CTS/USART1_NSS,FDCAN1_RX,LCD_R4,EVENTOUT|OTG_FS_DM|
|N1|5|BOOT0|I|-|-|
|P4|6|PI11|I/O|MCO1,I2S_CKIN,LCD_G6,EVENTOUT|WKUP5|
|N4|7|BOOT1|I|-|-|
|AC19|8|OTG_VBUS|A|-|OTG_FS_VBUS,OTG_HS_VBUS|
|M2|9|BOOT2|I |-|-|
|-|10|GND|S|-|-|
|-|11|GND|S|-|-|
|AC10|12|PD11|I/O|LPTIM2_IN2,I2C4_SMBA,I2C1_SMBA,USART3_CTS/USART3_NSS,QUADSPI_BK1_IO0,SAI2_SD_A,FMC_A16/FMC_CLE,EVENTOUT|-|
|F3|13|PI5|I/O|TIM8_CH1,SAI2_SCK_A,DCMI_VSYNC,LCD_B5,EVENTOUT|-|
|Y18|14|PD12|I/O|LPTIM1_IN1,TIM4_CH1,LPTIM2_IN1,I2C4_SCL,I2C1_SCL,USART3_RTS/USART3_DE,QUADSPI_BK1_IO1,SAI2_FS_A,FMC_A17/FMC_ALE,EVENTOUT|-|
|F2|15|PI7|I/O|TIM8_CH3,SAI2_FS_A,DCMI_D7,LCD_B7,EVENTOUT|-|
|AB12|16|PF7|I/O|TIM17_CH1,SPI5_SCK,SAI1_MCLK_B,UART7_TX,QUADSPI_BK1_IO2,EVENTOUT|-|
|F4|17|PI6|I/O|TIM8_CH2,SAI2_SD_A,DCMI_D6,LCD_B6,EVENTOUT|-|
|AA13|18|PF6|I/O|TIM16_CH1,SPI5_NSS,SAI1_SD_B,UART7_RX,QUADSPI_BK1_IO3,SAI4_SCK_B, EVENTOUT|-|
|D6|19|PE0|I/O|LPTIM1_ETR,TIM4_ETR,LPTIM2_ETR,SPI3_SCK/I2S3_CK,SAI4_MCLK_B,UART8_RX,SAI2_MCLK_A,FMC_NBL0,DCMI_D2, EVENTOUT|-|
|AA11|20|PE7|I/O|TIM1_ETR,TIM3_ETR,DFSDM1_DATIN2,UART7_RX,QUADSPI_BK2_IO0,FMC_AD4/FMC_D4,EVENTOUT|-|
|Y10|21|PF11|I/O|SPI5_MOSI,SAI2_SD_B,DCMI_D12,LCD_G5,EVENTOUT|ADC1_INP2|
|AC13|22|PE8|I/O|TIM1_CH1N,DFSDM1_CKIN2,UART7_TX,QUADSPI_BK2_IO1,FMC_AD5/FMC_D5,EVENTOUT|-|
|Y13|23|PG9|I/O|DBTRGO,USART6_RX,SPDIFRX_IN3,QUADSPI_BK2_IO2,SAI2_FS_B,FMC_NE2/FMC_NCE,DCMI_VSYNC,LCD_R1,EVENTOUT|-|
|AA9|24|PE9|I/O|TIM1_CH1,DFSDM1_CKOUT,UART7_RTS/UART7_DE,QUADSPI_BK2_IO2,FMC_AD6/FMC_D6，EVENTOUT|-|
|-|25|GND|S|-|-|
|Y15|26|PE10|I/O|TIM1_CH2N,DFSDM1_DATIN4,UART7_CTS,QUADSPI_BK2_IO3,FMC_AD7/FMC_D7,EVENTOUT|-|
|D18|27|PC8|I/O|TRACED0,TIM3_CH3,TIM8_CH3,UART4_TX,USART6_CK,UART5_RTS/UART5_DE,SDMMC1_D0,DCMI_D2,EVENTOUT|-|
|Y16|28|PB2|I/O|TRACED4,RTC_OUT2,SAI1_D1,DFSDM1_CKIN1,USART1_RX,I2S_CKIN,SAI1_SD_A,SPI3_MOSI/I2S3_SDO,UART4_RX,QUADSPI_CLK,EVENTOUT|-|
|D17|29|PC9|I/O|TRACED1,TIM3_CH4,TIM8_CH4,I2C3_SDA,I2S_CKIN,UART5_CTS,QUADSPI_BK1_IO0,SDMMC1_D1,DCMI_D3,LCD_B2,EVENTOUT|-|
|-|30|GND|S|-|-|
|D15|31|PC10|I/O|TRACED2,DFSDM1_CKIN5,SPI3_SCK/I2S3_CK,USART3_TX,UART4_TX,QUADSPI_BK1_IO1,SAI4_MCLK_B,SDMMC1_D2,DCMI_D8,LCD_R2,EVENTOUT|-|
|B3|32|PH4|I/O|I2C2_SCL,LCD_G5,LCD_G4,EVENTOUT|-|
|D16|33|PC11|I/O|TRACED3,DFSDM1_DATIN5,SPI3_MISO/I2S3_SDI,USART3_RX,UART4_RX,QUADSPI_BK2_NCS,SAI4_SCK_B,SDMMC1_D3,DCMI_D4,EVENTOUT|-|
|A2|34|PH5|I/O|I2C2_SDA,SPI5_NSS,SAI4_SD_B,EVENTOUT|-|
|D12|35|PD2|I/O|TIM3_ETR,I2C5_SMBA,UART4_RX,UART5_RX,SDMMC1_CMD,DCMI_D11,EVENTOUT|-|
|J4|36|PZ2|I/O|I2C6_SCL,I2C2_SCL,I2C5_SMBA,SPI1_MOSI/I2S1_SDO,I2C4_SMBA,USART1_TX,SPI6_MOSI,EVENTOUT|-|
|D13|37|PC12|I/O|TRACECLK,MCO2,SAI4_D3,SPI3_MOSI/I2S3_SDO,USART3_CK,UART5_TX,SAI4_SD_B,SDMMC1_CK,DCMI_D9,EVENTOUT|-|
|G1|38|PZ1|I/O|I2C6_SDA,I2C2_SDA,I2C5_SDA,SPI1_MISO/I2S1_SDI,I2C4_SDA,USART1_RX,SPI6_MISO,EVENTOUT|-|
|E1|39|PI3|I/O|TIM8_ETR,SPI2_MOSI/I2S2_SDO,DCMI_D10,EVENTOUT|-|
|G3|40|PZ0|I/O|HDP1,UART4_RX,FDCAN1_RX,LCD_VSYNC,EVENTOUT|-|
|-|41|GND|S|-|-|
|AA14|42|PF9|I/O|TRACED13,TIM17_CH1N,SPI5_MOSI,SAI1_FS_B,UART7_CTS,TIM14_CH1,QUADSPI_BK1_IO1,EVENTOUT|-|
|A17|43|DSI_D1N|A|-|-|
|W4|44|PH7|I/O|I2C3_SCL,SPI5_MISO,ETH1_GMII_RXD3/ETH1_MII_RXD3/ETH1_RGMII_RXD3,MDIOS_MDC,DCMI_D9,EVENTOUT|-|
|B17|45|DSI_D1P|A|-|-|
|Y11|46|PH6|I/O|TIM12_CH1,I2C2_SMBA,SPI5_SCK,ETH1_GMII_RXD2/ETH1_MII_RXD2/ETH1_RGMII_RXD2,MDIOS_MDIO,DCMI_D8,EVENTOUT|-|
|-|47|GND|S|-|-|
|-|48|GND|S|-|-|
|A16|49|DSI_CKN|A|-|-|
|L4|50|PI8|I/O|EVENTOUT|RTC_OUT2/RTC_LSCO,TAMP_IN2/TAMP_OUT3,WKUP4|
|B16|51|DSI_CKP|A|-|-|
|J3|52|PZ7|I/O|I2C6_SDA,I2C2_SDA,USART1_TX,EVENTOUT|-|
|-|53|GND|S|-|-|
|H1|54|PZ6|I/O|I2C6_SCL,I2C2_SCL,USART1_CK,I2S1_MCK,I2C4_SMBA,USART1_RX,EVENTOUT|-|
|B15|55|DSI_D0N|A|-|-|
|G4|56|PZ3|I/O|I2C6_SDA,I2C2_SDA,I2C5_SDA,SPI1_NSS/I2S1_WS,I2C4_SDA,USART1_CTS/USART1_NSS,SPI6_NSS,EVENTOUT|-|
|C15|57|DSI_D0P|A|-|-|
|H2|58|PZ5|I/O|I2C6_SDA,I2C2_SDA,I2C5_SDA,I2C4_SDA,USART1_RTS/USART1_DE,EVENTOUT|-|
|-|59|GND|S|-|-|
|D8|60|PF0|I/O|I2C2_SDA,SDMMC3_D0,SDMMC3_CKIN,FMC_A0,EVENTOUT|-|
|A14|61|PF2|I/O|I2C2_SMBA,SDMMC2_D0DIR,SDMMC3_D0DIR,SDMMC1_D0DIR,FMC_A2,EVENTOUT|-|
|D9|62|PF4|I/O|USART2_RX,SDMMC3_D1,SDMMC3_D123DIR,FMC_A4,EVENTOUT|-|
|AA19|63|PD13|I/O|LPTIM1_OUT,TIM4_CH2,I2C4_SDA,I2C1_SDA,I2S3_MCK,QUADSPI_BK1_IO3,SAI2_SCK_A,FMC_A18,DSI_TE,EVENTOUT|-|
|A7|64|PD5|I/O|USART2_TX,SDMMC3_D2,FMC_NWE,EVENTOUT|-|
|C19|65|PA15|I/O|DBTRGI,TIM2_CH1/TIM2_ETR,SAI4_D2,SDMMC1_CDIR,CEC,SPI1_NSS/I2S1_WS,SPI3_NSS/I2S3_WS,SPI6_NSS,UART4_RTS/UART4_DE,SDMMC2_D5,SDMMC2_CDIR,SDMMC1_D5,SAI4_FS_A,UART7_TX,LCD_R1,EVENTOUT|-|
|D10|66|PD7|I/O|TRACED6,DFSDM1_DATIN4,I2C2_SCL,DFSDM1_CKIN1,USART2_CK,SPDIFRX_IN0,SDMMC3_D3,FMC_NE1,EVENTOUT|-|
|D19|67|PE4|I/O|TRACED1,SAI1_D2,DFSDM1_DATIN3,TIM15_CH1N,SPI4_NSS,SAI1_FS_A,SDMMC2_CKIN,SDMMC1_CKIN,SDMMC2_D4,SDMMC1_D4,FMC_A20,DCMI_D4,LCD_B|-|
|A5|68|PF1|I/O|I2C2_SCL,SDMMC3_CMD,SDMMC3_CDIR,FMC_A1,EVENTOUT|-|
|-|69|GND|S||-|
|B7|70|PG15|I/O|TRACED7,SAI1_D2,I2C2_SDA,SAI1_FS_A,USART6_CTS/USART6_NSS,SDMMC3_CK,DCMI_D13,EVENTOUT|-|

- **8.70-PIN接口:** 可以从下面的表格来查找每个引脚对应的功能

|Pin 封装编号|Pin 编号|Pin 名称|Pin 类型|可选择的功能|附加功能|
|:---:|:---:|:---:|:---:|:---:|:---:|
|Y3|1|PB10|I/O|TIM2_CH3,LPTIM2_IN1,I2C2_SCL,SPI2_SCK/I2S2_CK,DFSDM1_DATIN7,USART3_TX,QUADSPI_BK1_NCS,ETH1_GMII_RX_ER/ETH1_MII_RX_ER,LCD_G4,EVENTOUT|-|
|AC7|2|PC4|I/O|DFSDM1_CKIN2,I2S1_MCK,SPDIFRX_IN2,ETH1_GMII_RXD0/ETH1_MII_RXD0/ETH1_RGMII_RXD0/ETH1_RMII_RXD0,EVENTOUT|ADC1_INP4,ADC2_INP4|
|AC5|3|PB12|I/O|TIM1_BKIN,I2C6_SMBA,I2C2_SMBA,SPI2_NSS/I2S2_WS,DFSDM1_DATIN1,USART3_CK,USART3_RX,FDCAN2_RX,ETH1_GMII_TXD0/ETH1_MII_TXD0/ETH1_RGMII_TXD0/ETH1_RMII_TXD0,UART5_RX,EVENTOUT|-|
|AB7|4|PC5|I/O|SAI1_D3,DFSDM1_DATIN2,SAI4_D4,SAI1_D4,SPDIFRX_IN3,ETH1_GMII_RXD1/ETH1_MII_RXD1/ETH1_RGMII_RXD1/ETH1_RMII_RXD1,SAI4_D3,EVENTOUT|ADC1_INP8,ADC1_INN4,ADC2_INP8,ADC2_INN4|
|W2|5|PC3|I/O|-TRACECLK,DFSDM1_DATIN1,SPI2_MOSI/I2S2_SDO,ETH1_GMII_TX_CLK/ETH1_MII_TX_CLK,EVENTOUT|ADC1_INP13,ADC1_INN12|
|AB6|6|PB0|I/O|TIM1_CH2N,TIM3_CH3,TIM8_CH2N,DFSDM1_CKOUT,UART4_CTS,LCD_R3,ETH1_GMII_RXD2/ETH1_MII_RXD2/ETH1_RGMII_RXD2,MDIOS_MDIO,LCD_G1,EVENTOUT|ADC1_INP9,ADC1_INN5,ADC2_INP9,ADC2_INN5|
|Y14|7|PB6|I/O|TIM16_CH1N,TIM4_CH1,I2C1_SCL,CEC,I2C4_SCL,USART1_TX,FDCAN2_TX,QUADSPI_BK1_NCS,DFSDM1_DATIN5,UART5_TX,DCMI_D5,EVENTOUT|-|
|AA7|8|PB1|I/O|TIM1_CH3N,TIM3_CH4,TIM8_CH3N,DFSDM1_DATIN1,LCD_R6,ETH1_GMII_RXD3/ETH1_MII_RXD3/ETH1_RGMII_RXD3,MDIOS_MDC,LCD_G0,EVENTOUT|ADC1_INP5,ADC2_INP5|
|W1|9|PG1|I/O|TRACED1,ETH1_GMII_TXD5,FMC_A11,EVENTOUT|-|
|AB8|10|PA7|I/O|TIM1_CH1N,TIM3_CH2,TIM8_CH1N,SAI4_D1,SPI1_MOSI/I2S1_SDO,SPI6_MOSI,TIM14_CH1,QUADSPI_CLK,ETH1_GMII_RX_DV/ETH1_MII_RX_DV/ETH1_RGMII_RX_CTL/ETH1_RMII_CRS_DV,SAI4_SD_A,EVENTOUT|ADC1_INP7,ADC1_INN3,ADC2_INP7,ADC2_INN3|
|Y17|11|PA10|I/O|TIM1_CH3,SPI3_NSS/I2S3_WS,USART1_RX,MDIOS_MDIO,SAI4_FS_B,DCMI_D1,LCD_B1,EVENTOUT|OTG_FS_ID,OTG_HS_ID|
|Y6|12|PG5|I/O|TIM1_ETR,ETH1_GMII_CLK125/ETH1_RGMII_CLK125,FMC_A15,EVENTOUT|-|
|-|13|GND|S|-|-|
|AA4|14|PA1|I/O|ETH_CLK,TIM2_CH2,TIM5_CH2,LPTIM3_OUT,TIM15_CH1N,USART2_RTS/USART2_DE,UART4_RX,QUADSPI_BK1_IO3,SAI2_MCLK_B,ETH1_GMII_RX_CLK/ETH1_MII_RX_CLK/ETH1_RGMII_RX_CLK/ETH1_RMII_REF_CLK,LCD_R2,EVENTOUT|ADC1_INP17,ADC1_INN16|
|K3|15|PD8|I/O|DFSDM1_CKIN3,SAI3_SCK_B,USART3_TX,SPDIFRX_IN1,FMC_AD13/FMC_D13,LCD_B7,EVENTOUT|-|
|-|16|GND|S|-|-|
|AB10|17|PB8|I/O|HDP6,TIM16_CH1,TIM4_CH3,DFSDM1_CKIN7,I2C1_SCL,SDMMC1_CKIN,I2C4_SCL,SDMMC2_CKIN,UART4_RX,FDCAN1_RX,SDMMC2_D4,ETH1_GMII_TXD3/ETH1_MII_TXD3/ETH1_RGMII_TXD3,SDMMC1_D4,DCMI_D6,LCD_B6,EVENTOUT|-|
|AB2|18|PG4|I/O|TIM1_BKIN2,ETH1_GMII_GTX_CLK/ETH1_RGMII_GTX_CLK,FMC_A14,EVENTOUT|-|
|U2|19|PA3|I/O|TIM2_CH4,TIM5_CH4,LPTIM5_OUT,TIM15_CH2,USART2_RX,LCD_B2,ETH1_GMII_COL/ETH1_MII_COL,LCD_B5,EVENTOUT|ADC1_INP15,PVD_IN|
|AA2|20|PG13|I/O|TRACED0,LPTIM1_OUT,SAI1_CK2,SAI4_CK1,SPI6_SCK,SAI1_SCK_A,USART6_CTS/USART6_NSS,SAI4_MCLK_A,ETH1_GMII_TXD0/ETH1_MII_TXD0/ETH1_RGMII_TXD0/ETH1_RMII_TXD0,FMC_A24,LCD_R0, EVENTOUT|-|
|E4|21|PI4|I/O|TIM8_BKIN,SAI2_MCLK_A,DCMI_D5,LCD_B4,EVENTOUT|-|
|AA1|22|PG14|I/O|TRACED1,LPTIM1_ETR,SPI6_MOSI,SAI4_D1,USART6_TX,QUADSPI_BK2_IO3,SAI4_SD_A,ETH1_GMII_TXD1/ETH1_MII_TXD1/ETH1_RGMII_TXD1/ETH1_RMII_TXD1,FMC_A25,LCD_B0,EVENTOUT|-|
|B5|23|PD10|I/O|RTC_REFIN,TIM16_BKIN,DFSDM1_CKOUT,I2C5_SMBA,SPI3_MISO/I2S3_SDI,SAI3_FS_B,USART3_CK,FMC_AD15/FMC_D15,LCD_B3,EVENTOUT|-|
|Y2|24|PC2|I/O|DFSDM1_CKIN1,SPI2_MISO/I2S2_SDI,DFSDM1_CKOUT,ETH1_GMII_TXD2/ETH1_MII_TXD2/ETH1_RGMII_TXD2,DCMI_PIXCLK,EVENTOUT|ADC1_INP12,ADC1_INN11|
|AB11|25|PG10|I/O|TRACED10,UART8_CTS,LCD_G3,SAI2_SD_B,QUADSPI_BK2_IO2,FMC_NE3,DCMI_D2,LCD_B2,EVENTOUT|-|
|Y1|26|PE2|I/O|TRACECLK,SAI1_CK1,I2C4_SCL,SPI4_SCK,SAI1_MCLK_A,QUADSPI_BK1_IO2,ETH1_GMII_TXD3/ETH1_MII_TXD3/ETH1_RGMII_TXD3,FMC_A23,EVENTOUT|-|
|K4|27|PG12|I/O|LPTIM1_IN1,SPI6_MISO,SAI4_CK2,USART6_RTS/USART6_DE,SPDIFRX_IN1,LCD_B4,SAI4_SCK_A,ETH1_PHY_INTN,FMC_NE4,LCD_B1,EVENTOUT|-|
|AB1|28|PB11|I/O|TIM2_CH4,LPTIM2_ETR,I2C2_SDA,DFSDM1_CKIN7,USART3_RX,ETH1_GMII_TX_EN/ETH1_MII_TX_EN/ETH1_RGMII_TX_CTL/ETH1_RMII_TX_EN,DSI_TE,LCD_G5,EVENTOUT|-|
|K1|29|PD9|I/O|DFSDM1_DATIN3,SAI3_SD_B,USART3_RX,FMC_AD14/FMC_D14,DCMI_HSYNC,LCD_B0,EVENTOUT|-|
|-|30|GND|S|-|-|
|E2|31|PI2|I/O|TIM8_CH4,SPI2_MISO/I2S2_SDI,DCMI_D9,LCD_G7,EVENTOUT|-|
|AA6|32|PC1|I/O|TRACED0,SAI1_D1,DFSDM1_DATIN0,DFSDM1_CKIN4,SPI2_MOSI/I2S2_SDO,SAI1_SD_A,SDMMC2_CK,ETH1_MDC,MDIOS_MDC,EVENTOUT|ADC1_INP11,ADC1_INN10,ADC2_INP11,ADC2_INN10,TAMP_IN3,WKUP6|
|E3|33|PI1|I/O|TIM8_BKIN2,SPI2_SCK/I2S2_CK,DCMI_D8,LCD_G6,EVENTOUT|-|
|AC3|34|PA2|I/O|TIM2_CH3,TIM5_CH3,LPTIM4_OUT,TIM15_CH1,USART2_TX,SAI2_SCK_B,SDMMC2_D0DIR,ETH1_MDIO,MDIOS_MDIO,LCD_R1,EVENTOUT|ADC1_INP14,
WKUP2|
|C1|35|PI0|I/O|TIM5_CH4,SPI2_NSS/I2S2_WS,DCMI_D13,LCD_G5,EVENTOUT|-|
|-|36|GND|S|-|-|
|B1|37|PH15|I/O|TIM8_CH3N,DCMI_D11,LCD_G4,EVENTOUT|-|
|AC2|38|PG0|I/O|TRACED0,DFSDM1_DATIN0,ETH1_GMII_TXD4,FMC_A10,EVENTOUT|-|
|C3|39|PH14|I/O|TIM8_CH2N,UART4_RX,FDCAN1_RX,DCMI_D4,LCD_G3,EVENTOUT|-|
|V2|40|PG2|I/O|TRACED2,MCO2,TIM8_BKIN,ETH1_GMII_TXD6,FMC_A12,EVENTOUT|-|
|D1|41|PH13|I/O|TIM8_CH1N,UART4_TX,FDCAN1_TX,LCD_G2,EVENTOUT|-|
|AB9|42|PG8|I/O|TRACED15,TIM2_CH1/TIM2_ETR,ETH_CLK,TIM8_ETR,SPI6_NSS,SAI4_D2,USART6_RTS/USART6_DE,USART3_RTS/USART3_DE,SPDIFRX_IN2,SAI4_FS_A,ETH1_PPS_OUT,LCD_G7,EVENTOUT|-|
|C10|43|PE6|I/O|TRACED2,TIM1_BKIN2,SAI1_D1,TIM15_CH2,SPI4_MOSI,SAI1_SD_A,SDMMC2_D0,SDMMC1_D2,SAI2_MCLK_B,FMC_A22,DCMI_D7,LCD_G1,EVENTOUT|-|
|-|44|GND|S|-|-|
|C6|45|PE14|I/O|TIM1_CH4,SPI4_MOSI,UART8_RTS/UART8_DE,SAI2_MCLK_B,SDMMC1_D123DIR,FMC_AD11/FMC_D11,LCD_G0,LCD_CLK,EVENTOUT|-|
|B14|46|PC6|I/O|HDP1,TIM3_CH1,TIM8_CH1,DFSDM1_CKIN3,I2S2_MCK,USART6_TX,SDMMC1_D0DIR,SDMMC2_D0DIR,SDMMC2_D6,DSI_TE,SDMMC1_D6,DCMI_D0,LCD_HSYNC,EVENTOUT|-|
|D3|47|PE15|I/O|HDP3,TIM1_BKIN,TIM15_BKIN,USART2_CTS/USART2_NSS,UART8_CTS,FMC_NCE2,FMC_AD12/FMC_D12,LCD_R7,EVENTOUT|-|
|C2|48|PH10|I/O|TIM5_CH1,I2C4_SMBA,I2C1_SMBA,DCMI_D1,LCD_R4,EVENTOUT|-|
|B2|49|PH12|I/O|HDP2,TIM5_CH3,I2C4_SDA,I2C1_SDA,DCMI_D3,LCD_R6,EVENTOUT|-|
|C4|50|PH11|I/O|TIM5_CH2,I2C4_SCL,I2C1_SCL,DCMI_D2,LCD_R5,EVENTOUT|-|
|AB5|51|PC0|I/O|DFSDM1_CKIN0,LPTIM2_IN2,DFSDM1_DATIN4,SAI2_FS_B,QUADSPI_BK2_NCS,LCD_R5,EVENTOUT|ADC1_INP10,ADC2_INP10|
|C8|52|PE1|I/O|LPTIM1_IN2,I2S2_MCK,SAI3_SD_B,UART8_TX,FMC_NBL1,DCMI_D3,EVENTOUT|-|
|V3|53|PA5|I/O|TIM2_CH1/TIM2_ETR,TIM8_CH1N,SAI4_CK1,SPI1_SCK/I2S1_CK,SPI6_SCK,SAI4_MCLK_A,LCD_R4,EVENTOUT|ADC1_INP19,ADC1_INN18,ADC2_INP19,ADC2_INN18,DAC_OUT2|
|A4|54|PE11|I/O|TIM1_CH2,DFSDM1_CKIN4,SPI4_NSS,USART6_CK,SAI2_SD_B,FMC_AD8/FMC_D8,DCMI_D4,LCD_G3,EVENTOUT|-|
|C5|55|PH9|I/O|TIM12_CH2,I2C3_SMBA,DCMI_D0,LCD_R3,EVENTOUT|-|
|D14|56|PD3|I/O|HDP5,DFSDM1_CKOUT,SPI2_SCK/I2S2_CK,DFSDM1_DATIN0,USART2_CTS/USART2_NSS,SDMMC1_D123DIR,SDMMC2_D7,SDMMC2_D123DIR,SDMMC1_D7,FMC_CLK,DCMI_D5,LCD_G7,EVENTOUT|-|
|D5|57|PH8|I/O|TIM5_ETR,I2C3_SDA,DCMI_HSYNC,LCD_R2,EVENTOUT|-|
|A3|58|PE13|I/O|HDP2,TIM1_CH3,DFSDM1_CKIN5,SPI4_MISO,SAI2_FS_B,FMC_AD10/FMC_D10,DCMI_D6,LCD_DE,EVENTOUT|-|
|AA3|59|PH3|I/O|DFSDM1_CKIN4,QUADSPI_BK2_IO1,SAI2_MCLK_B,ETH1_GMII_COL/ETH1_MII_COL,LCD_R1,EVENTOUT|-|
|B10|60|PB9|I/O|HDP7,TIM17_CH1,TIM4_CH4,DFSDM1_DATIN7,I2C1_SDA,SPI2_NSS/I2S2_WS,I2C4_SDA,SDMMC2_CDIR,UART4_TX,FDCAN1_TX,SDMMC2_D5,SDMMC1_CDIR,SDMMC1_D5,DCMI_D7,LCD_B7,EVENTOUT|-|
|AB4|61|PH2|I/O|LPTIM1_IN2,QUADSPI_BK2_IO0,SAI2_SCK_B,ETH1_GMII_CRS/ETH1_MII_CRS,LCD_R0,EVENTOUT|-|
|V4|62|PA4|I/O|HDP0,TIM5_ETR,SAI4_D2,SPI1_NSS/I2S1_WS,SPI3_NSS/I2S3_WS,USART2_CK,SPI6_NSS,SAI4_FS_A,DCMI_HSYNC,LCD_VSYNC,EVENTOUT|ADC1_INP18,ADC2_INP18,DAC_OUT1|
|AC14|63|PG7|I/O|TRACED5,SAI1_MCLK_A,USART6_CK,UART8_RTS/UART8_DE,QUADSPI_CLK,QUADSPI_BK2_IO3,DCMI_D13,LCD_CLK,EVENTOUT|-|
|D11|64|PB7|I/O|TIM17_CH1N,TIM4_CH2,I2C1_SDA,I2C4_SDA,USART1_RX,SDMMC2_D1,DFSDM1_CKIN5,FMC_NL,DCMI_VSYNC,EVENTOUT|-|
|Y12|65|PF10|I/O|TIM16_BKIN,SAI1_D3,SAI4_D4,SAI1_D4,QUADSPI_CLK,SAI4_D3,DCMI_D11,LCD_DE,EVENTOUT|-|
|AC8|66|PA6|I/O|TIM1_BKIN,TIM3_CH1,TIM8_BKIN,SAI4_CK2,SPI1_MISO/I2S1_SDI,SPI6_MISO,TIM13_CH1,MDIOS_MDC,SAI4_SCK_A,DCMI_PIXCLK,LCD_G2,EVENTOUT|ADC1_INP3,ADC2_INP3|
|T1|67|PI10|I/O|HDP0,USART3_CTS/USART3_NSS,ETH1_GMII_RX_ER/ETH1_MII_RX_ER,LCD_HSYNC,EVENTOUT|-|
|N2|68|PA13|I/O|DBTRGO,DBTRGI,MCO1,UART4_TX,EVENTOUT|BOOTFAILN|
|H4|69|PI9|I/O|HDP1,UART4_RX,FDCAN1_RX,LCD_VSYNC,EVENTOUT|-|
|B4|70|PE12|I/O|TIM1_CH3N,DFSDM1_DATIN5,SPI4_SCK,SDMMC1_D0DIR,SAI2_SCK_B,FMC_AD9/FMC_D9,LCD_B4,EVENTOUT|-|

## 资源下载
-----
- **[PDF]** [STM32MP157C Datasheet](https://github.com/SeeedDocument/Seeed-NPi-STM32MP157C/raw/master/Hardware/stm32mp157c.pdf)
- **[SCH]** [Seeed STM32MP157C SOM](https://github.com/SeeedDocument/Seeed-NPi-STM32MP157C/raw/master/Hardware/Seeed%20SoM%20-%20STM32MP157C%20v1.0_191212.pdf)
- **[SCH]** [Seeed STM32MP157C NPi](https://github.com/SeeedDocument/Seeed-NPi-STM32MP157C/raw/master/Hardware/Seeed%20NPi%20-%20STM32MP157C%20v1.0_191212.pdf)

## 技术支持

您可以将技术问题发送到 [forum](http://forum.seeedstudio.com/). <br /><p style="text-align:center"></p>

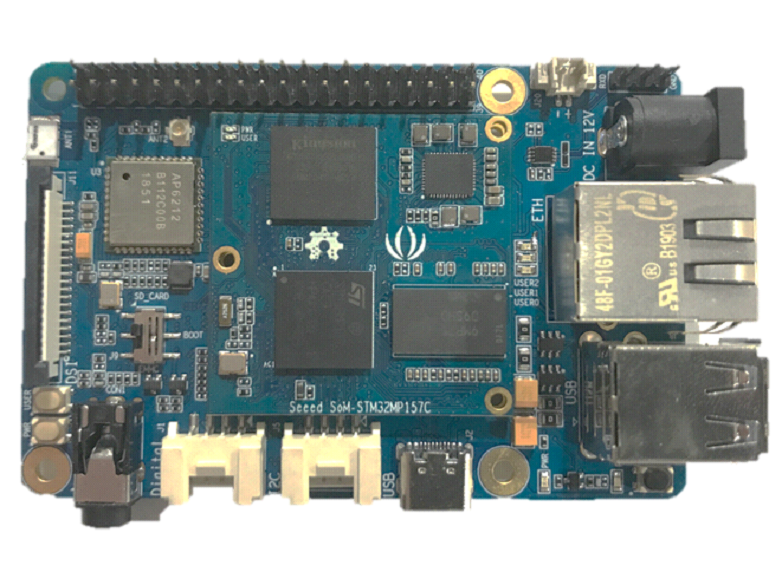
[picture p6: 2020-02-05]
IMG/overview.png

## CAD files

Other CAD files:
Hardware/st.skp

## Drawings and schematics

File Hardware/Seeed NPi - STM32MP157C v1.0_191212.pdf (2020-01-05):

# Initial Release

03 | 1000M Ethernet

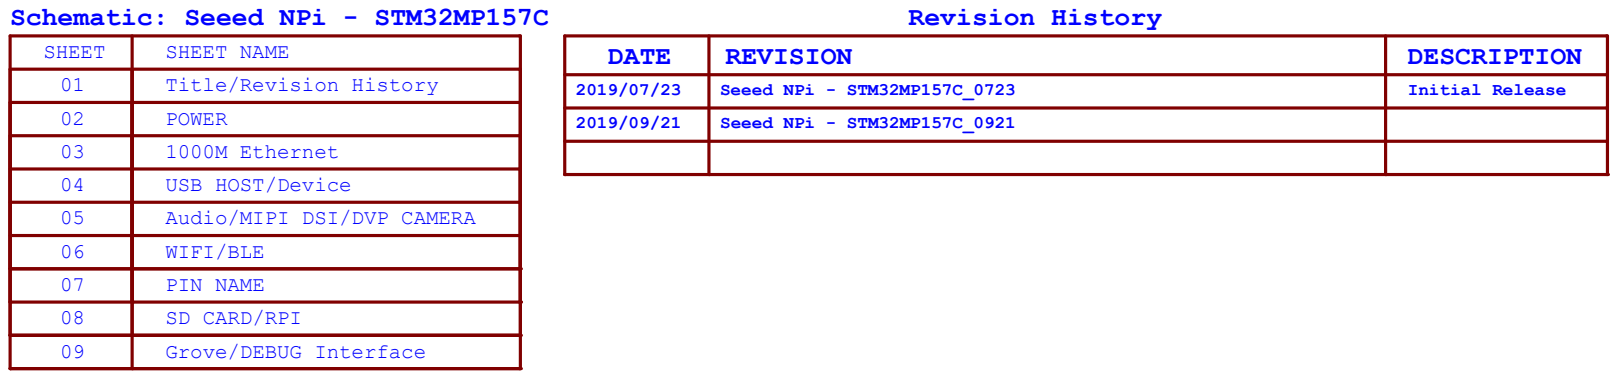
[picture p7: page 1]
Seeed NPi - STM32MP157C_0723; DESCRIPTION; DATE; Revision History; SHEET; SHEET NAME; REVISION; Schematic: Seeed NPi - STM32MP157C; Seeed NPi - STM32MP157C_0921; Title: Size:; Document Number:; Rev: Draw By:; Date:; Sheet:; https://www.seeedstudio.com A3; v1.01 weifeng; Monday, December 16, 2019; 9 Seeed NPi - STM32MP157C; 01 Title / Revision History Title: Size:

Title/Revision History
POWER

04 | USB HOST/Device
05 | Audio/MIPI DSI/DVP CAMERA
06 | WIFI/BLE
07 PIN NAME
08 SD CARD/RPI
09 Grove/DEBUG Interface

01 Title / Revision History

# Input Current:2A

# Output Current:3A

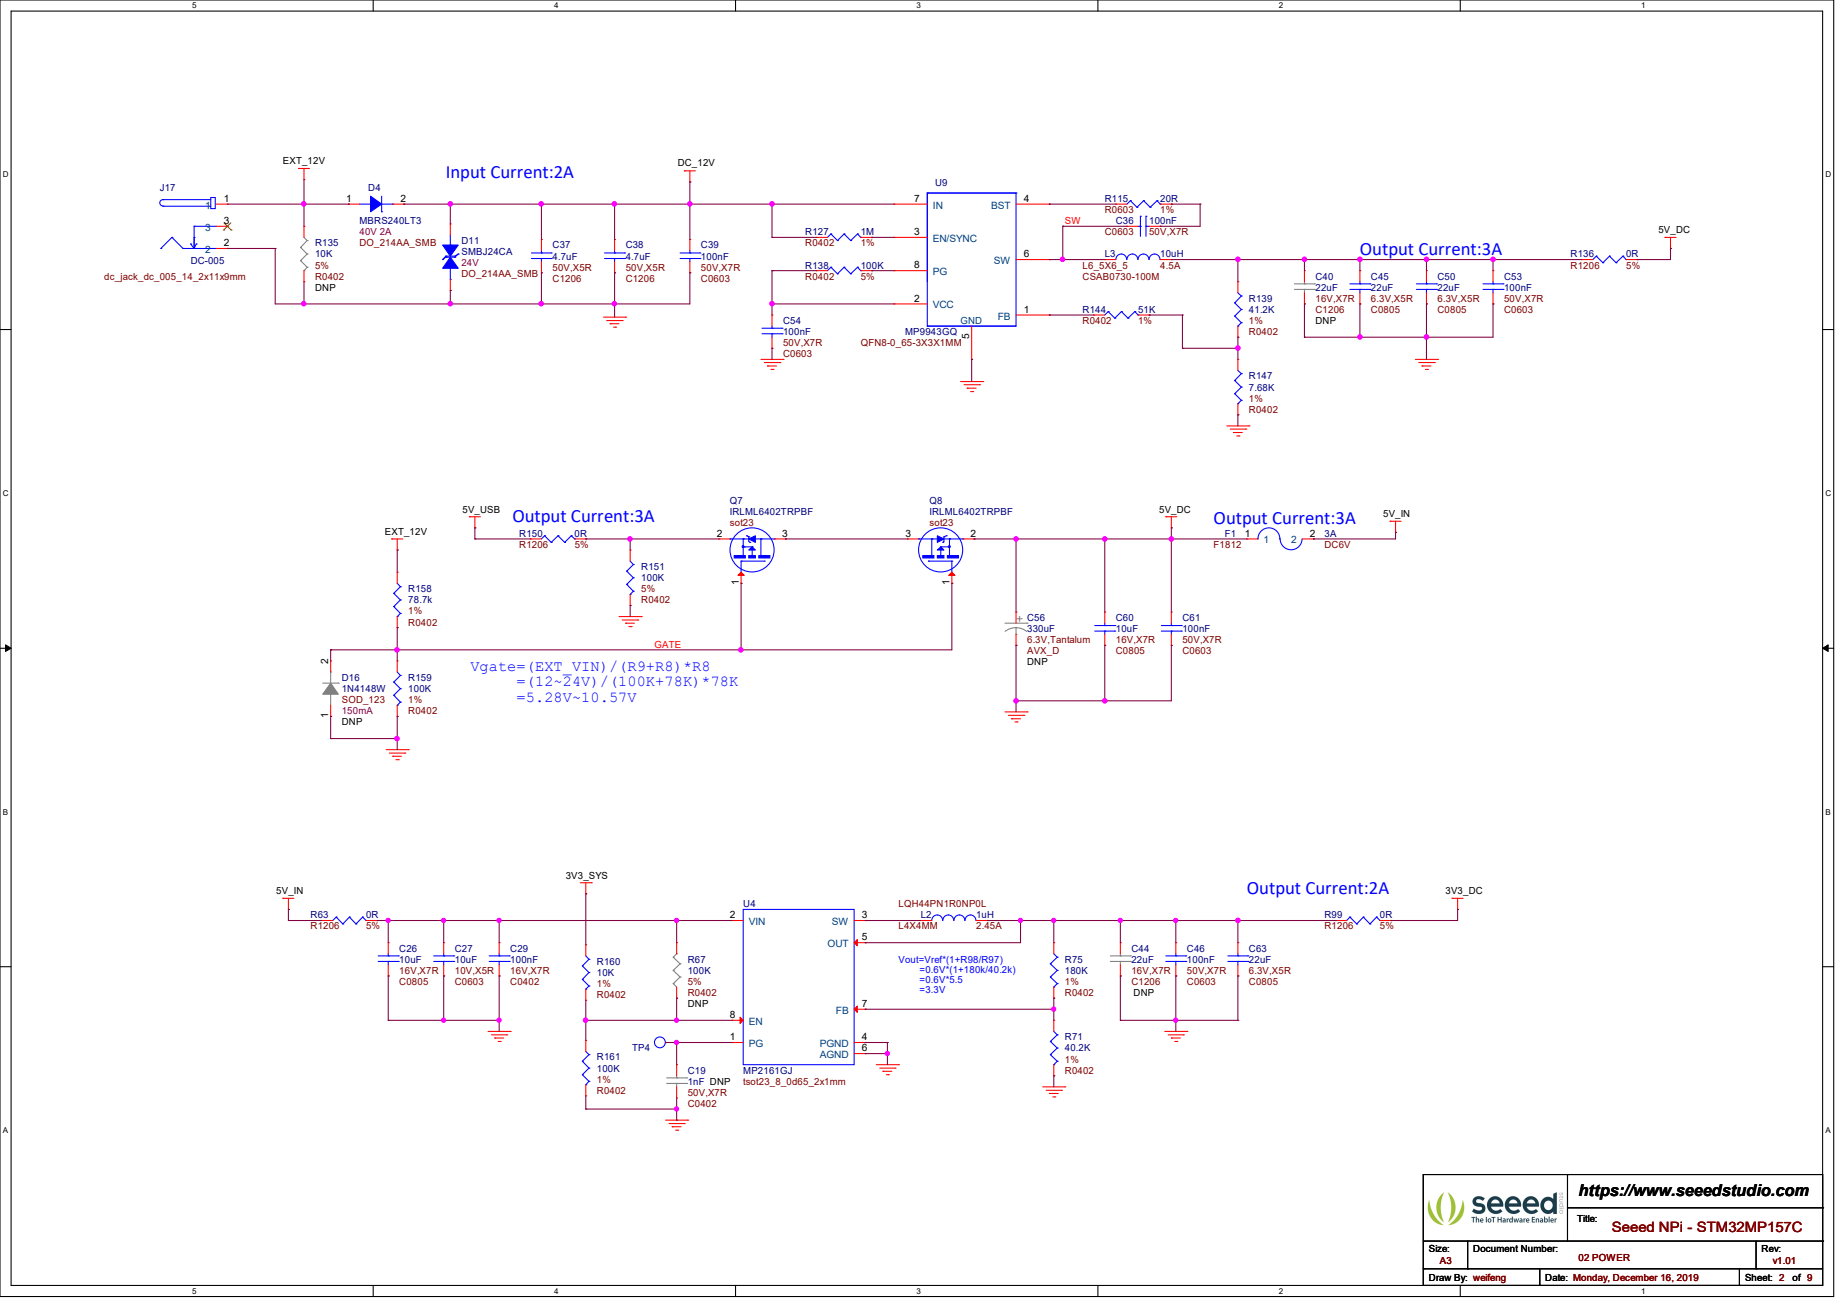
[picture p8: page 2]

# Pin33 PHY Address: 0 (Default) Dis 125MHz Output

# impedance. CLK125_EN:

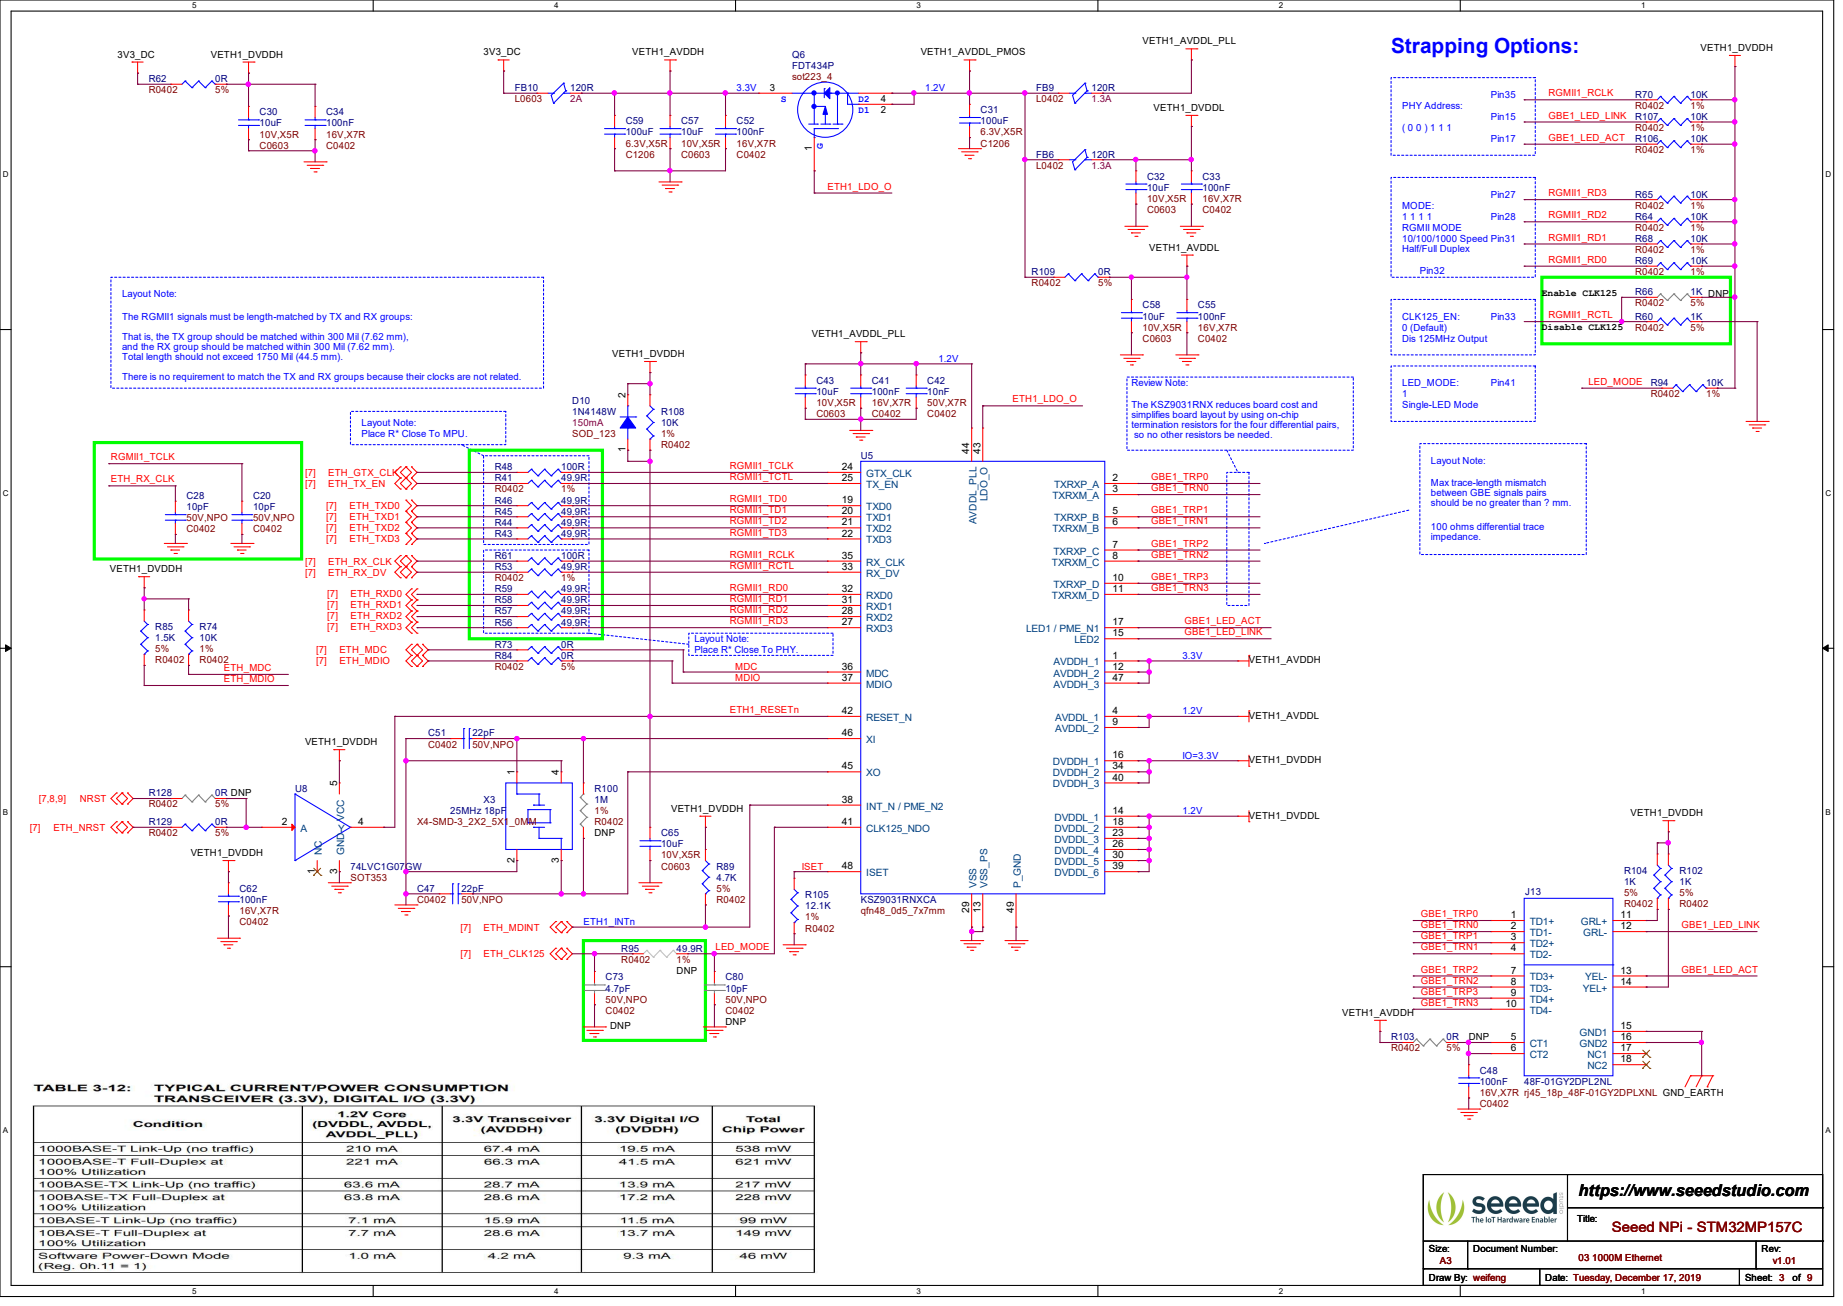
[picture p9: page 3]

LED_MODE: The KSZ9031RNX reduces board cost and

simplifies board layout by using on-chip
termination resistors for the four differential pairs,

between GBE signals pairs
should be no greater than ? mm.

# USB HOST

USB_A_Upper | USB_B_Lower

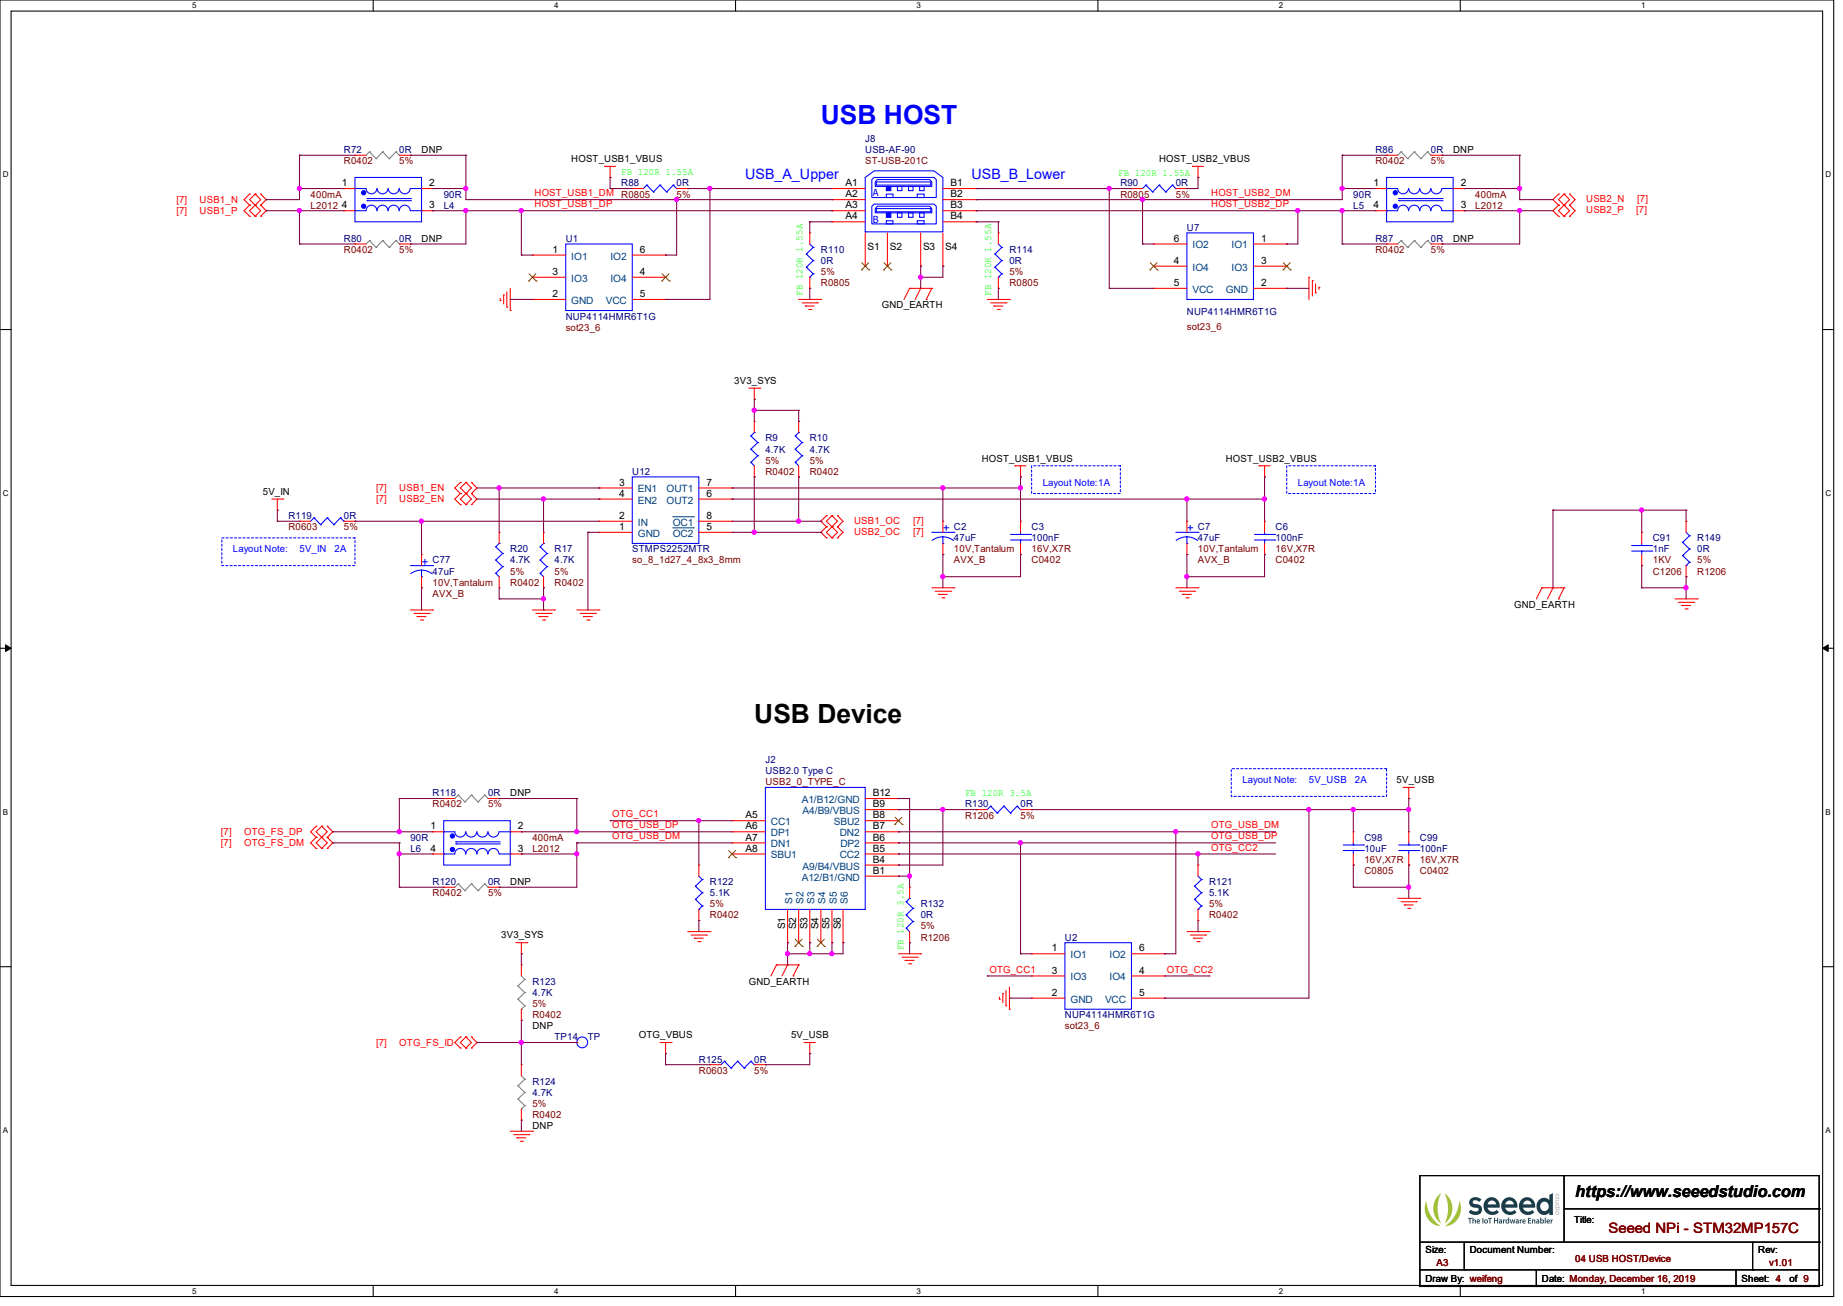
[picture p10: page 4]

# Serial Audio Interface (SAI)

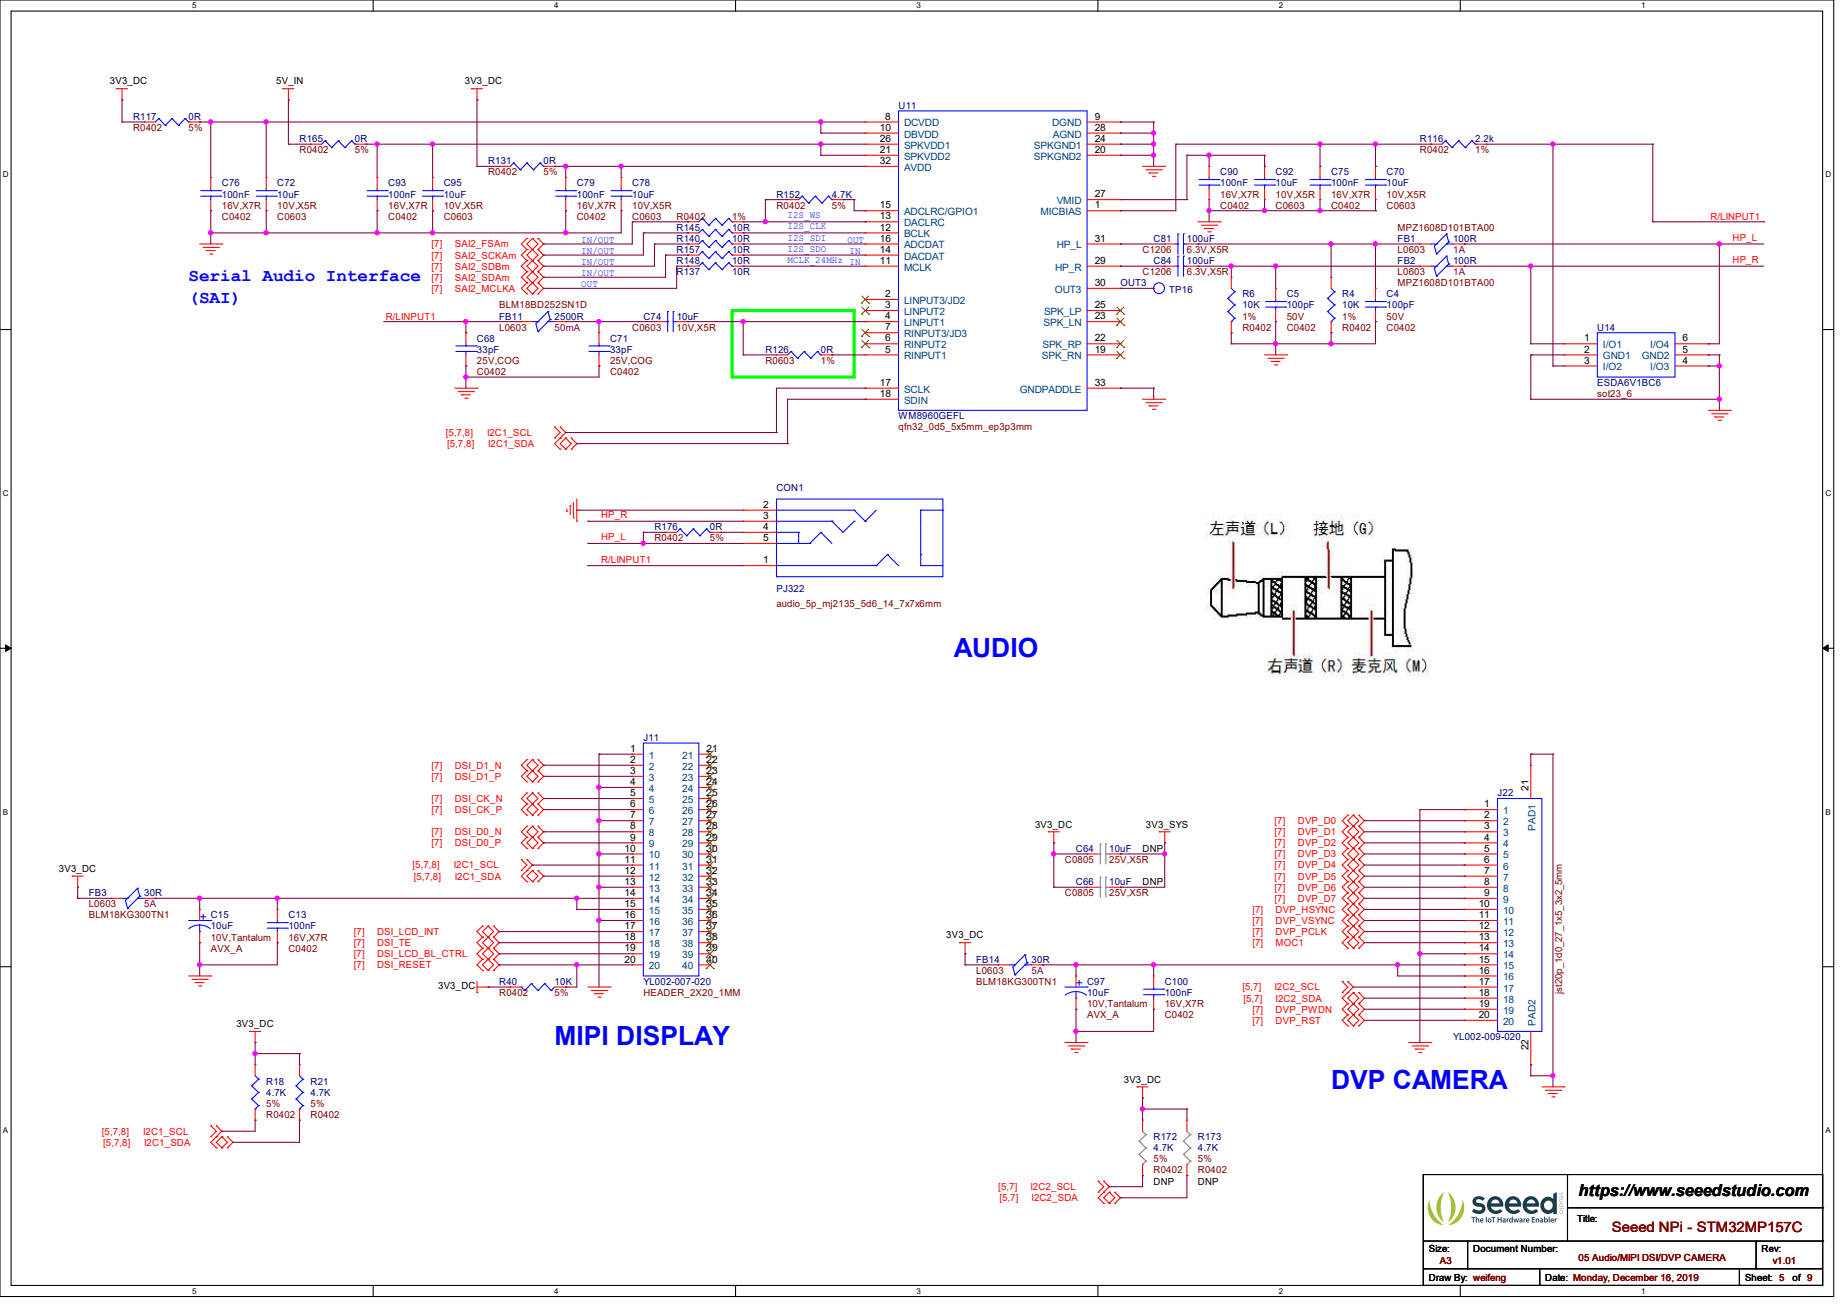
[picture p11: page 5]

U11 WM8960GEFL
DCVDD 8 DBVDD 10 SPKVDD1 26 SPKVDD2 21 AVDD 32 ADCLRC/GPIO1 15 DACLRC 13 BCLK 12 ADCDAT 16 DACDAT 14 MCLK 11

05 Audio/MIPI DSI/DVP CAMERA

# U3 AP6236 Module44-0_9-12X12X1_5MM

GND 1 | WL_BT_ANT 2 | GND_1 3 | FM_RX 4 | NC 5 | BT_WAKE 6 | BT_HOST_WAKE 7 | NC_1 8 | VBAT 9 | XTAL_IN 10 | XTAL_OUT 11 | WL_REG_ON 12 | WL_HOST_WAKE 13 | SDIO_DATA_2 14 | SDIO_DATA_3 15 | SDIO_DATA_CMD 16 | SDIO_DATA_CLK 17 | SDIO_DATA_0 18 | SDIO_DATA_1 19 | GND_2 20 | VIN_LDO_OUT 21 | VDDIO 22 | VIN_LDO | 23 LPO | 24 PCM_OUT | 25 PCM_CLK | 26 PCM_IN | 27 PCM_SYNC | 28 NC_2 | 29 NC_3 | 30 GND_3 | 31 NC_4 | 32 GND_4 | 33 BT_RST_N ³⁴ NC_5 35 GND_5 36 GPIO⁴ ³⁷ GPIO³ ³⁸ GPIO² ³⁹ GPIO¹ ⁴⁰ UART_RTS_N ⁴¹ UART_TXD ⁴² UART_RXD ⁴³ UART_CTS_N ⁴⁴ TP¹ ⁴⁵ TP² ⁴⁶ TP³ ⁴⁷ | FB7 | 120R

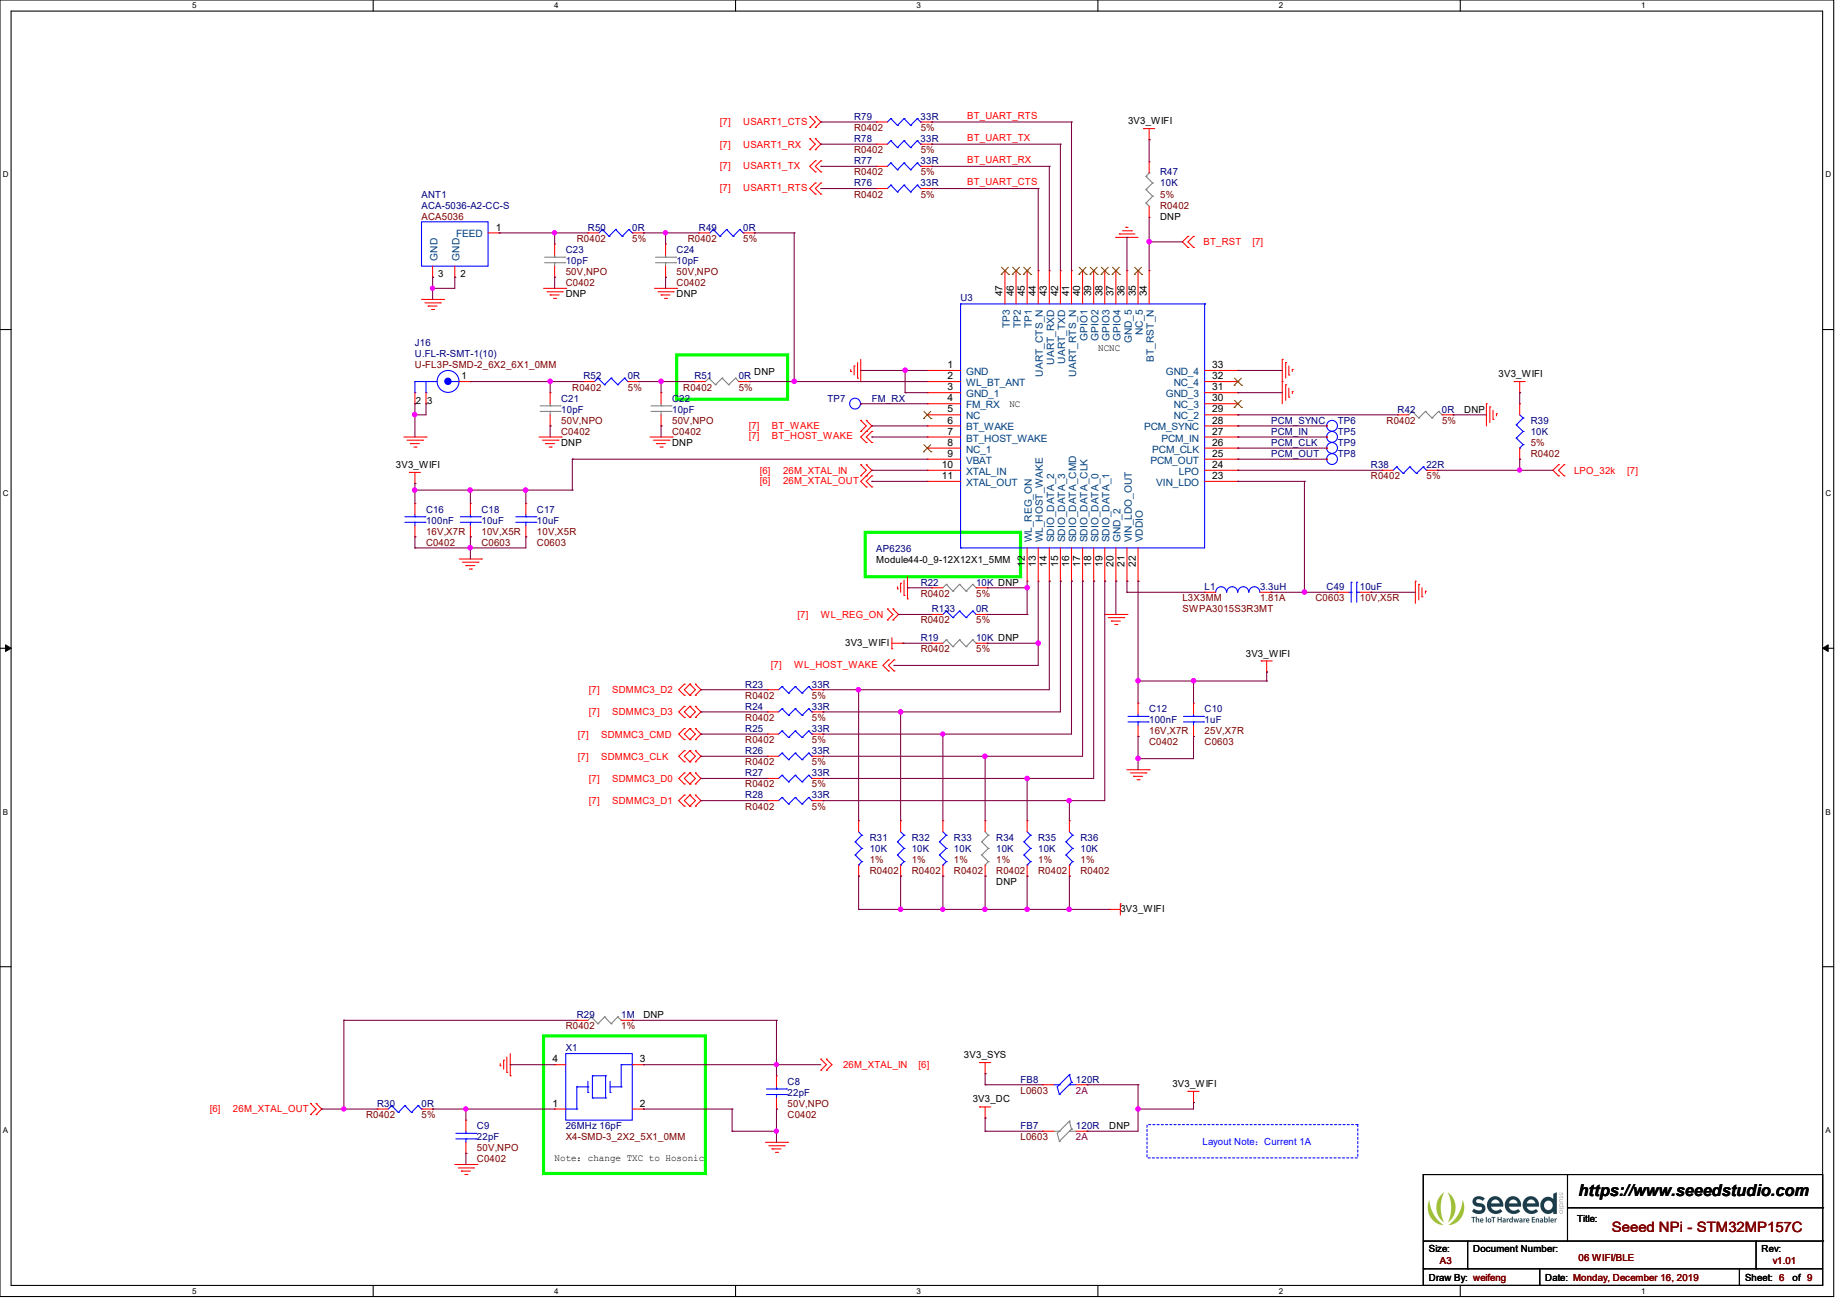
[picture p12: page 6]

Note：change TXC to Hosonic

# LTDC_G1HDMI_CEC

ETH_RX_DV [3] ETH_CLK125 [3] ETH_RX_CLK [3] ETH_GTX_CLK [3] ETH_TX_EN [3] ETH_MDC [3] ETH_MDIO [3] ETH_NRST [3] ETH_MDINT [3] DVP_D0 [5] DVP_D1 [5] DVP_D2 [5] DVP_D3 [5] DVP_D4 [5] DVP_D5 [5] DVP_D6 [5] DVP_D7 [5] DVP_HSYNC | [5] DVP_VSYNC | [5] DVP_PCLK [5] MOC1 [5] DVP_PWDN | [5]

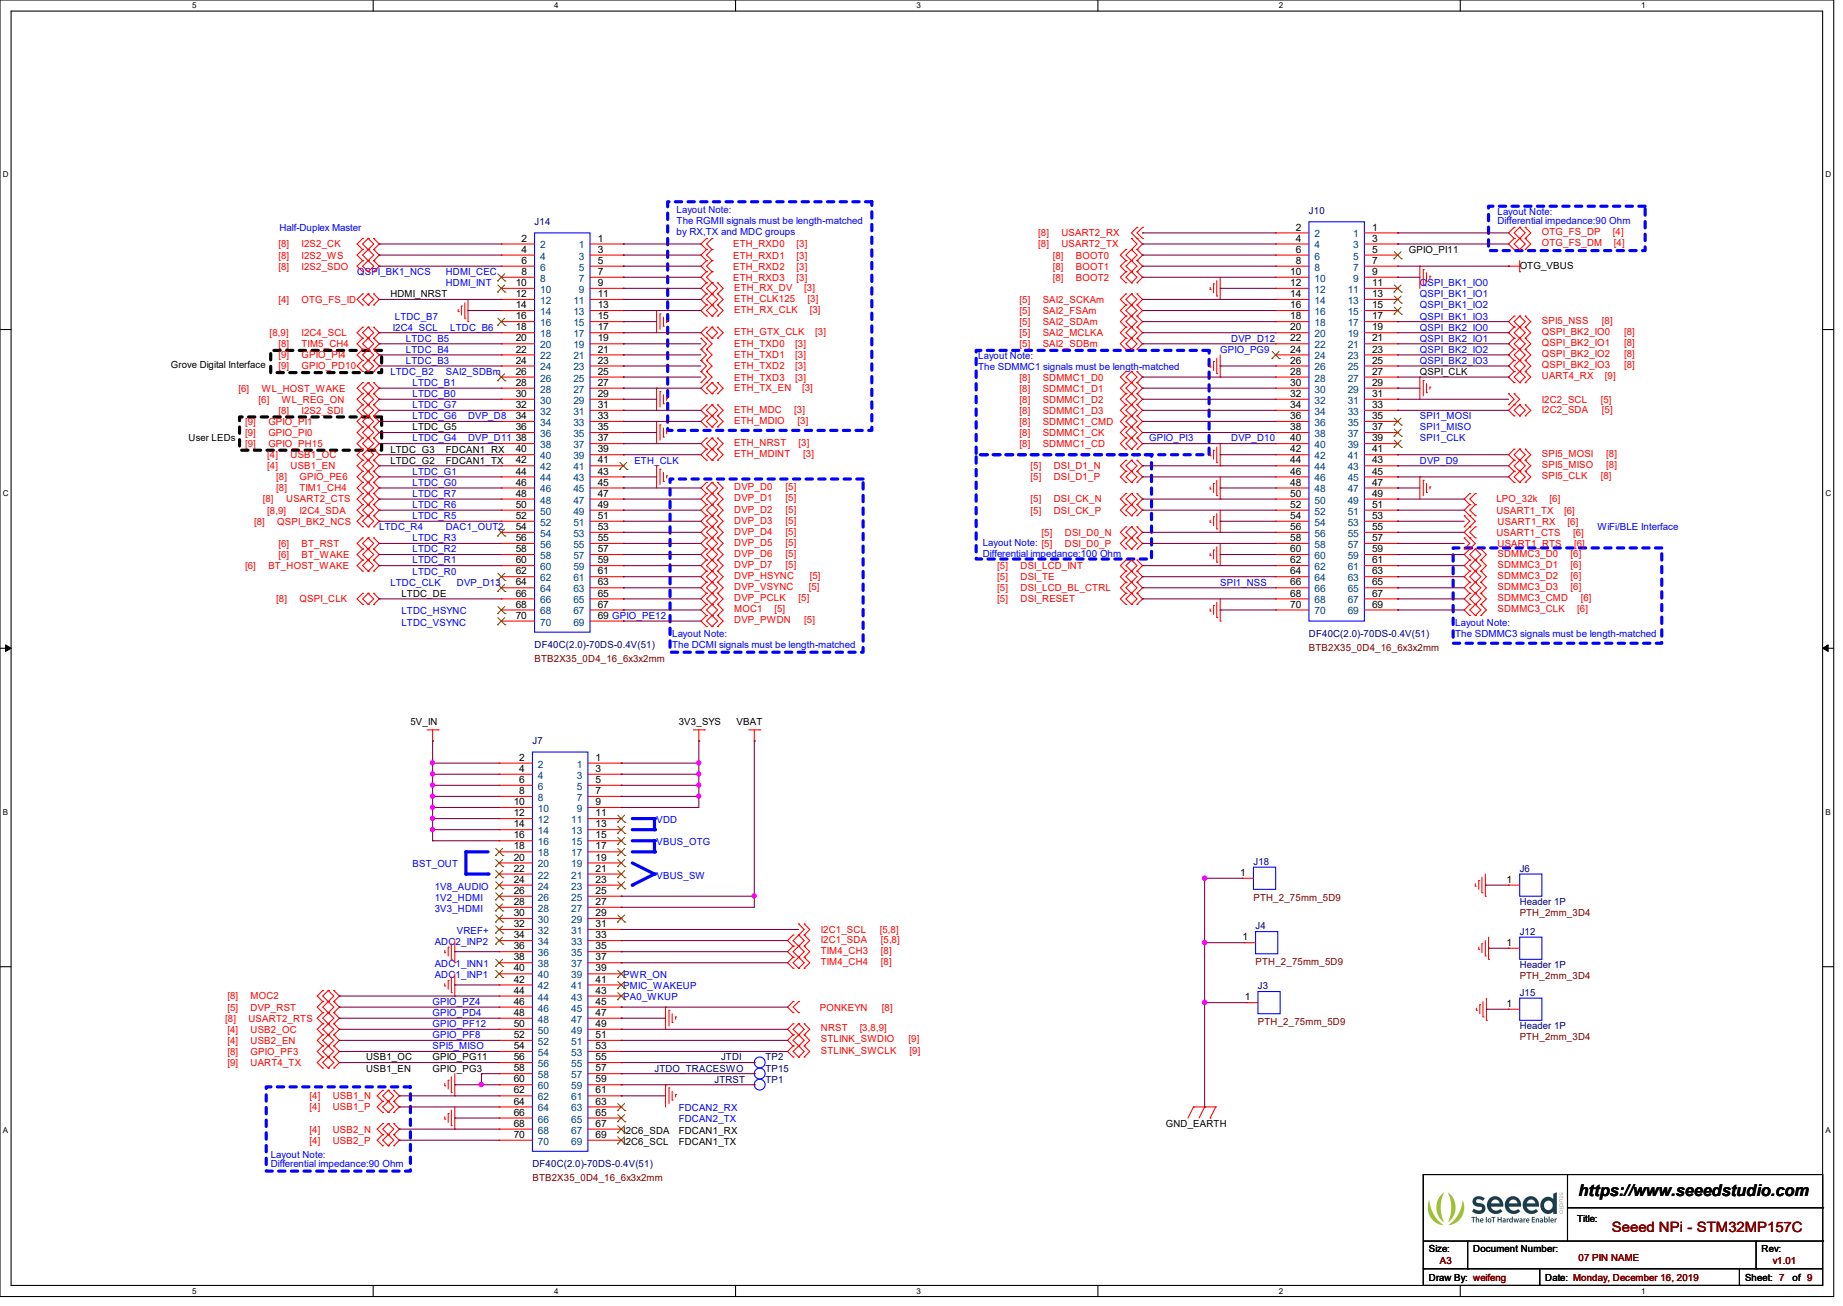
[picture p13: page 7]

Differential impedance:90 Ohm Layout Note: LTDC_B6

Layout Note:
The RGMII signals must be length-matched
by RX,TX and MDC groups
LTDC_G7DVP_D13 SAI2_SDBm
LTDC_B1
LTDC_B0

The SDMMC3 signals must be length-matched

The DCMI signals must be length-matched

# RPI Interface

# J19 Header 2x20 2.54mm

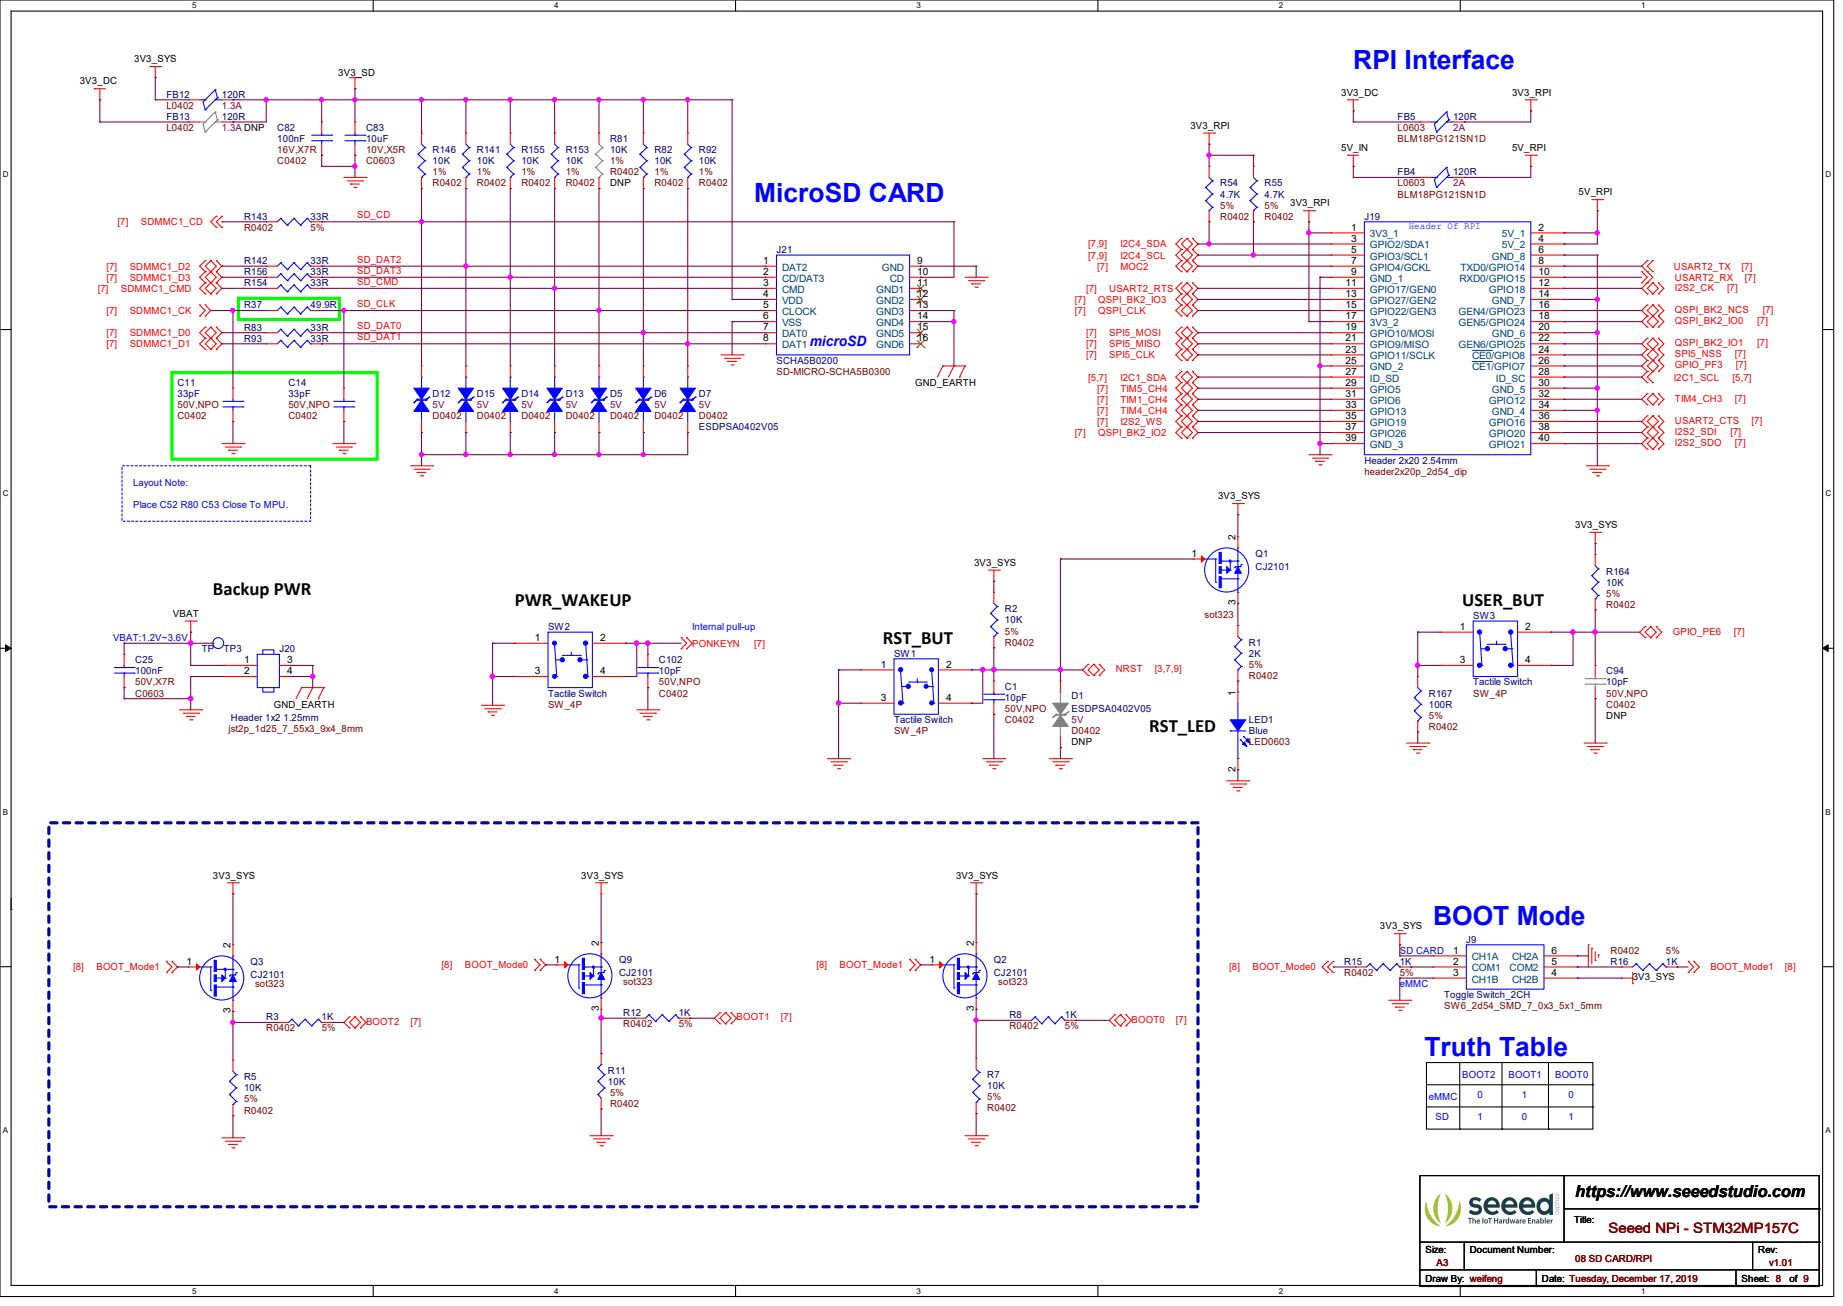
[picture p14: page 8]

MicroSD CARD Layout Note: Place C52 R80 C53 Close To MPU. VBAT:1.2V~3.6V

# USER_LED

USR1 | USR2 | USR0

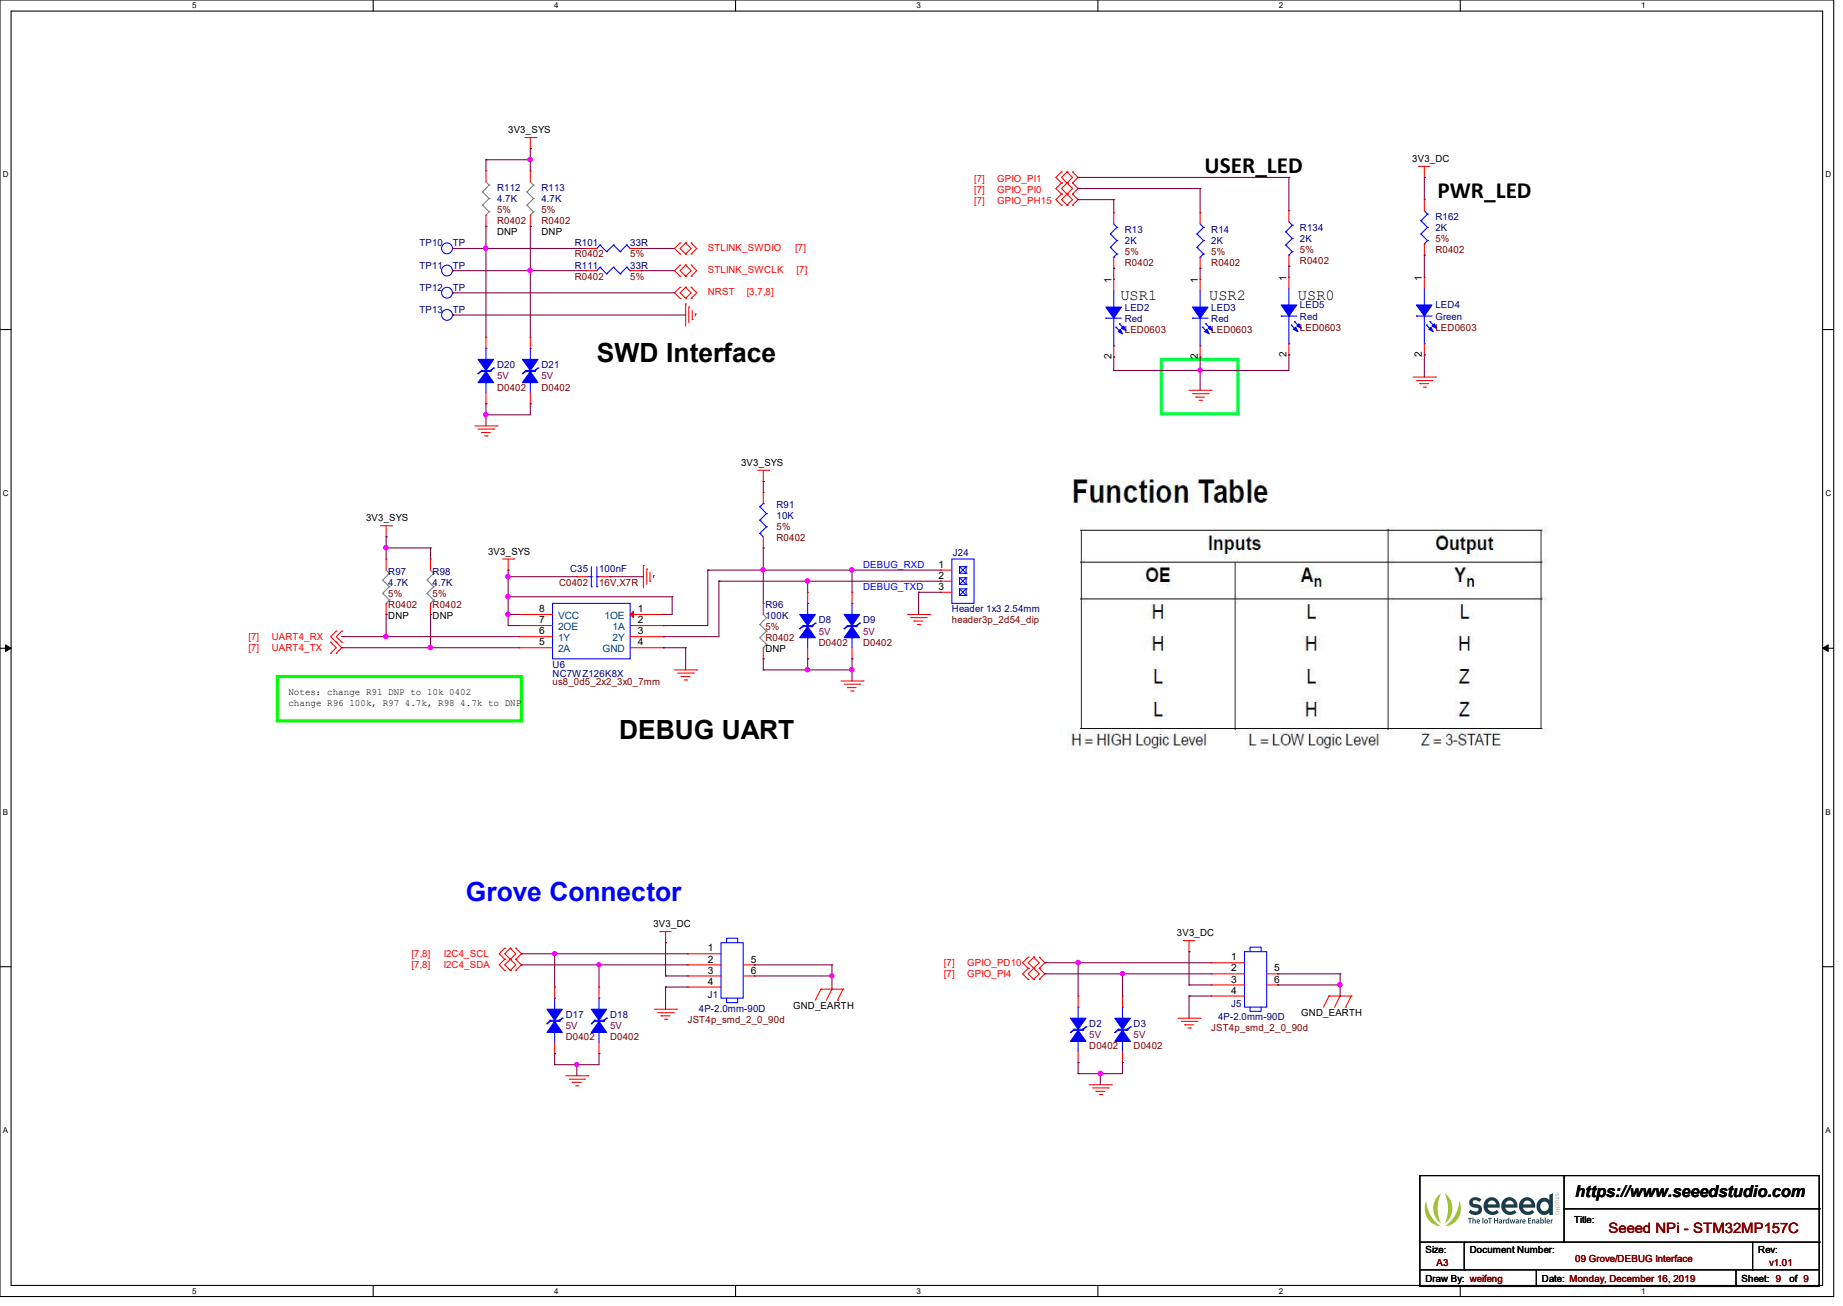
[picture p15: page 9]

Notes：change R91 DNP to 10k 0402
change R96 100k, R97 4.7k, R98 4.7k to DNP

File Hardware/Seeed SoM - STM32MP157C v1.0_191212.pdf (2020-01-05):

# Initial Release

03

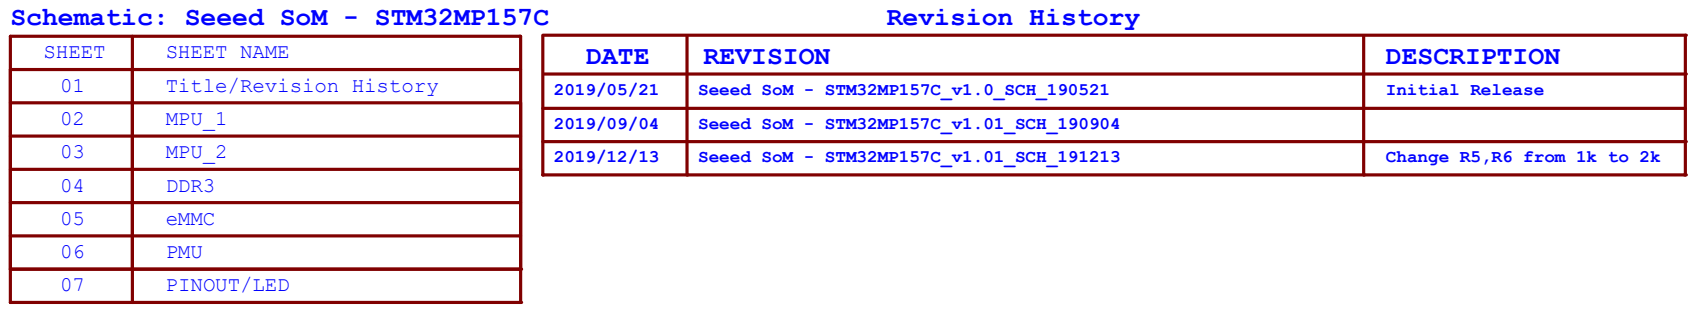
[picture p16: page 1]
Seeed SoM - STM32MP157C_v1.0_SCH_190521; DESCRIPTION; MPU_2; DATE; Title/Revision History; Revision History; SHEET; SHEET NAME; REVISION; Schematic: Seeed SoM - STM32MP157C; MPU_1; Seeed SoM - STM32MP157C_v1.01_SCH_190904; Seeed SoM - STM32MP157C_v1.01_SCH_191213; Change R5,R6 from 1k to 2k; Title: Size:; Document Number:; Rev: Draw By:; Date:; Sheet:; https://www.seeedstudio.com A3; v1.01 weifeng; Friday, December 13, 2019; 7 Seeed SoM - STM32MP157C; 01 Title / Revision History Title: Size:

04 | DDR3
05 | eMMC
06 | PMU
07 PINOUT/LED

01 Title / Revision History

I2S2_SDO | [7] DVP_D0 [7] SDMMC1_D0 [7] SDMMC1_D1 [7] SDMMC1_D2 [7] SDMMC1_D3 [7] SDMMC1_CK [7] SDMMC1_CMD [7] DVP_D5 [7] GPIO_PD4 | [7] SDMMC3_D2 [7] SDMMC3_D3 [7] LTDC_B7 [7] LTDC_B0 [7] LTDC_B3 [7] QSPI_BK1_IO0 | [7] QSPI_BK1_IO1 | [7] STLINK_SWDIO | [7] STLINK_SWCLK | [7] JTDI [7] JTDO_TRACESWO [7] JTRST [7]
ETH_RXD0 [7] ETH_RXD1 [7] FDCAN1_RX | [7] USART2_RX [7] ETH_TXD2 [7] FDCAN1_TX [7] DSI_TE [7]

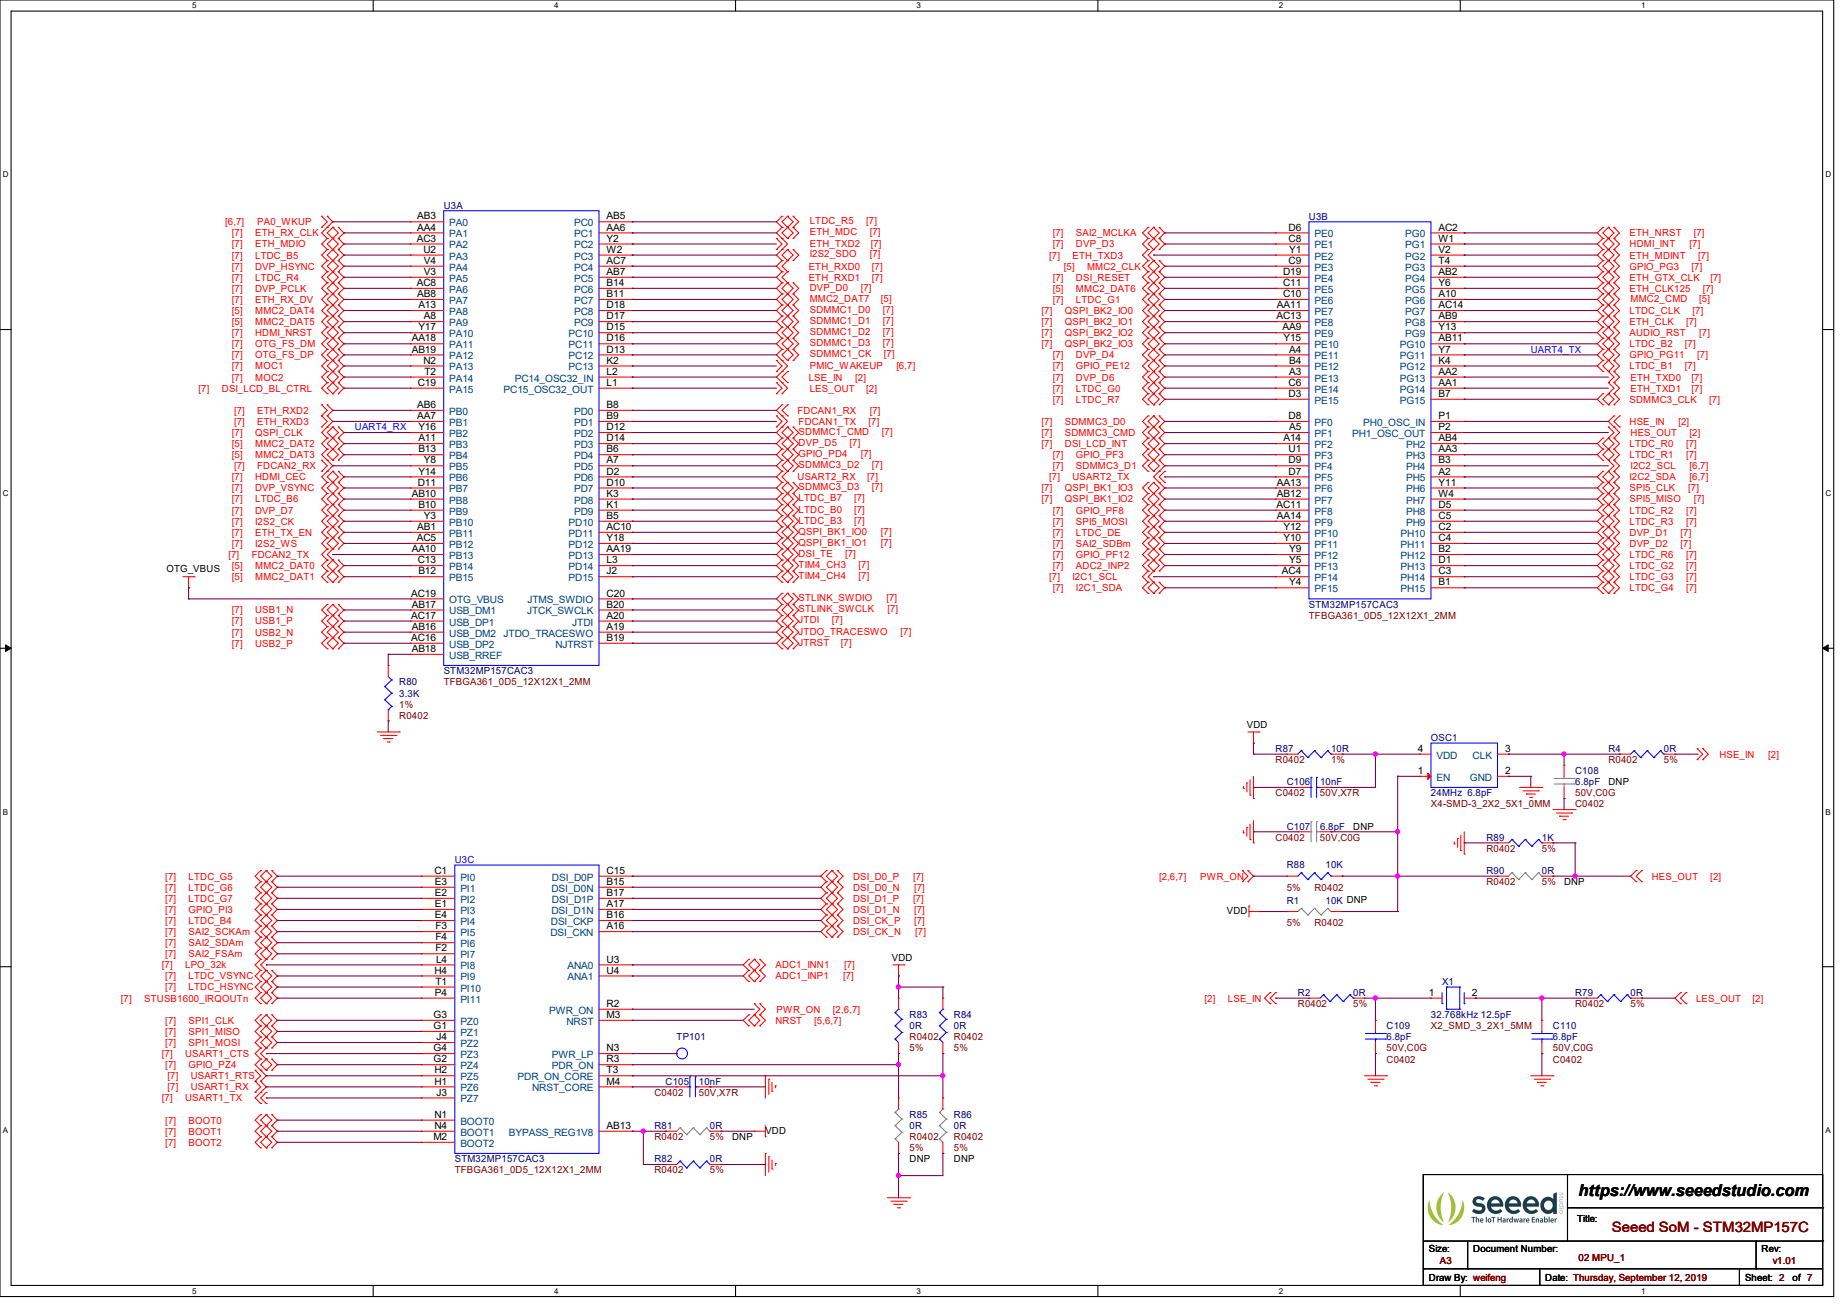
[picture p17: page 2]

VDDCORE1 1A2 VDDCORE2 1A4 VDDCORE3 1A6 VDDCORE4 1B1 VDDCORE5 1B3 VDDCORE6 1B5 VDDCORE7 1C2 VDDCORE8 1C4 VDDCORE9 1C6 VDDCORE10 1D1 VDDCORE11 1D3 VDDCORE12 1D5 VDDCORE13 1D7 VDDCORE14 1E2 VDDCORE15 1E4 VDDCORE16 1E6 VDDCORE17 1F5 VDDCORE18 1F7 VDDCORE19 1G6 VDDCORE20 1H7 VDD1 1F3 VDD2 1G4 VDD3 1H3 VDD4 1H5 VDD5 1J4 VDD6 1J6 VDDQ_DDR1 1A8 VDDQ_DDR2 1B7 VDDQ_DDR3 1B9 VDDQ_DDR4 1C8 VDDQ_DDR5 1D9 VDDQ_DDR6 1E8 VDDQ_DDR7 1F9 VDDQ_DDR8 1G8 VDDQ_DDR9 1H9 VDDQ_DDR10 1J8 VBAT 1F1 VDD_OTP 1J2 VDDA 1H1 VREF+ R4 VSSA 1H2 VDD_ANA 1G2 VDD_DSI B18 VDDA1V1_REG AB15 VDDA1V8_REG AB14 VDDA1V8_DSI C14 VDD1V2_DSI_PHY C17 VDD1V2_DSI_REG C18 VDD3V3_USBHS AA15 VDD3V3_USBFS AA17 VSS_USBHS AA16 VSS_DSI C16 VSS_ANA 1G1

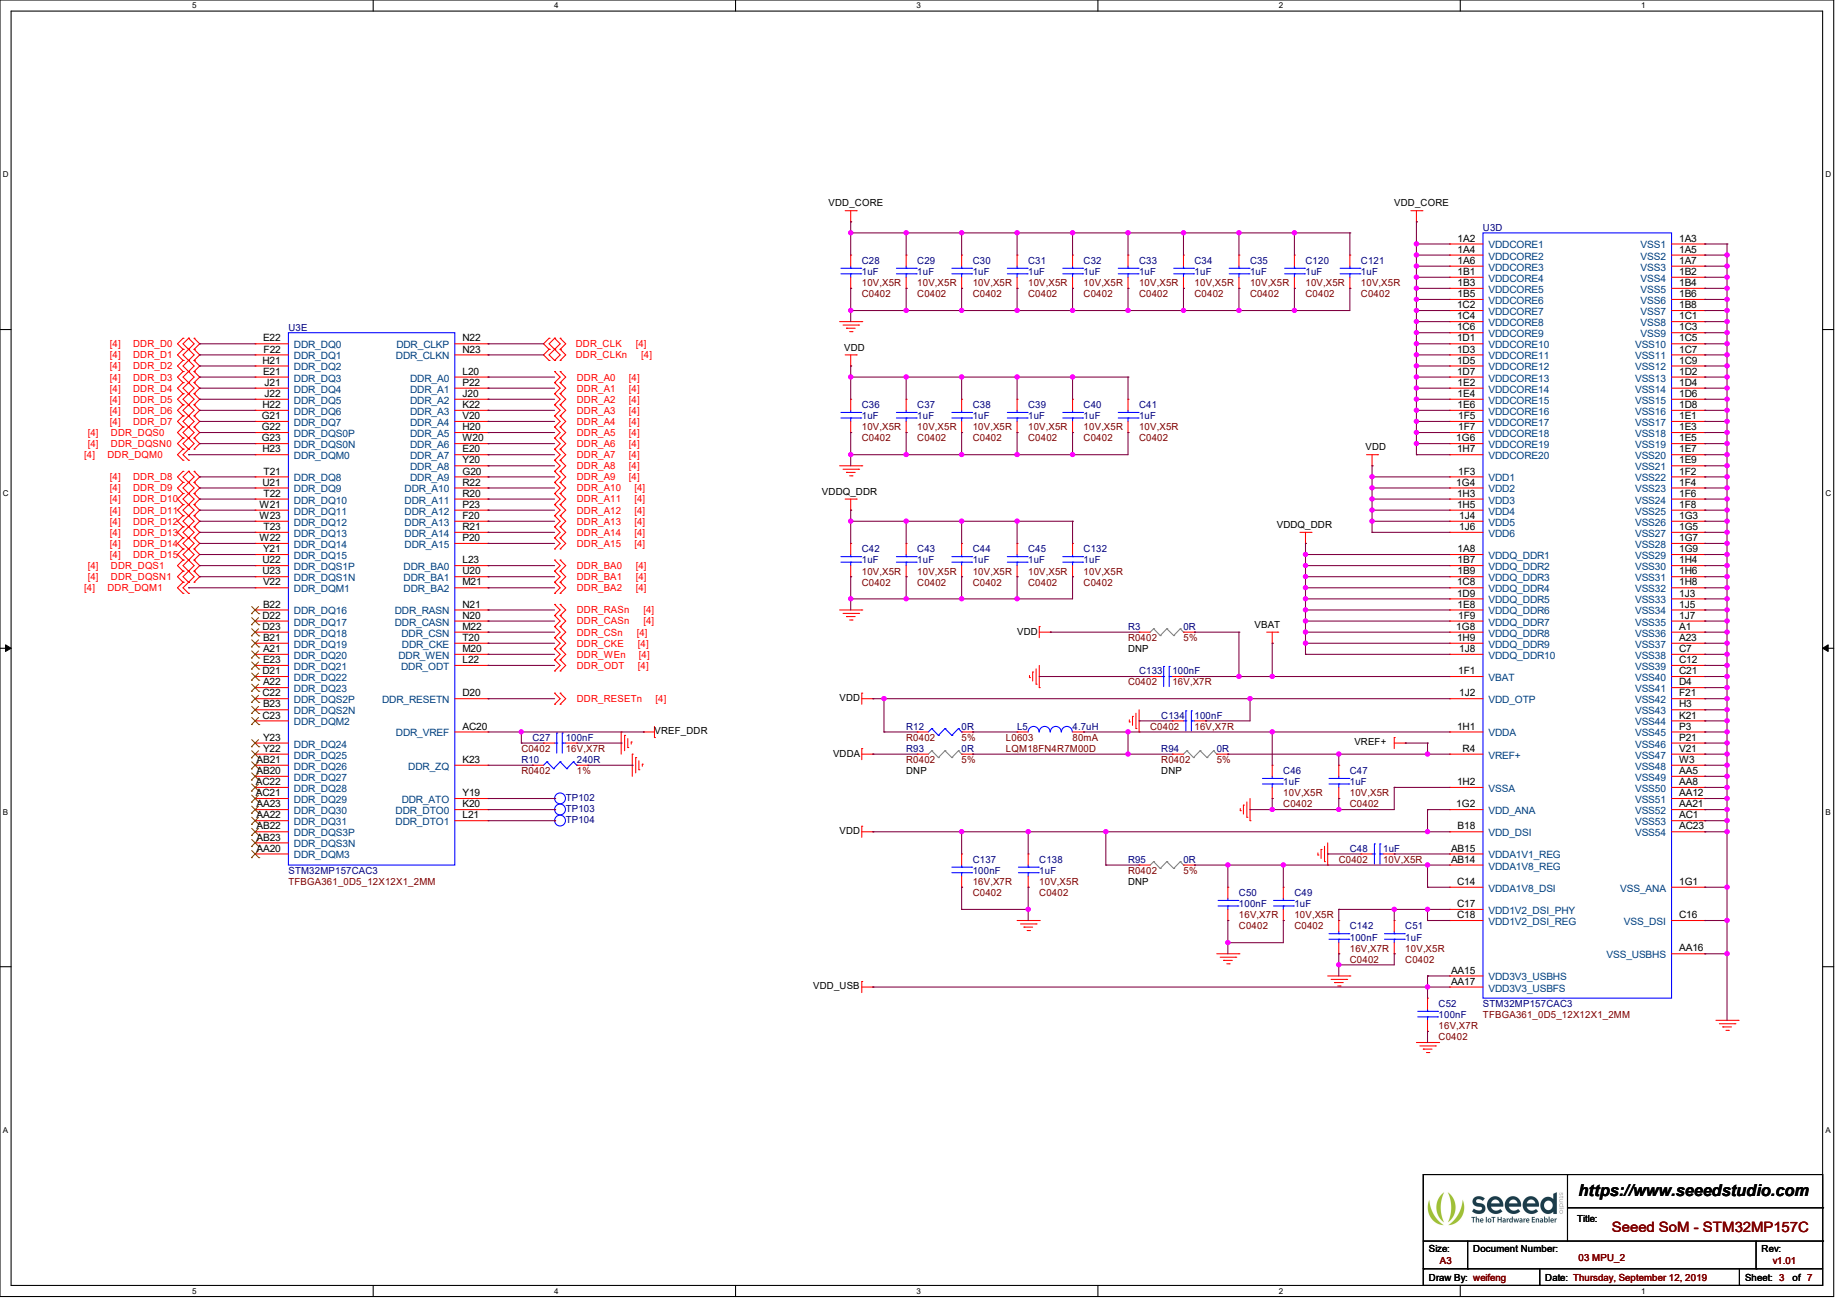
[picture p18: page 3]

# DDR3L SDRAM

CK J7 CKn K7 CKE K9 CSn L2 RASn J3 CASn K3 WEn L3 | A0 N3 A1 P7 A2 P3 A3 N2 A4 P8 A5 P2 A6 R8 A7 R2 A8 T8 A9 R3 A10 L7 A11 R7 A12 N7 A13 T3 A14 T7 BA0 M2 BA1 N8 BA2 M3 DQ0 E3 DQ1 F7 DQ2 F2 DQ3 F8 DQ4 H3 DQ5 H8 DQ6 G2 DQ7 H7 | ODT K1 VSS1 A9 VSS2 B3 VSS3 E1 VSS4 G8 VSSQ4 D8 VSSQ3 D1 VSSQ2 B9 VSSQ1 B1 VSSQ5 E2 VDDQ1 A1 VDDQ2 A8 VDDQ3 C1 VDDQ4 C9 VDDQ5 D2 | VDD1 B2 VDD2 G7 UDQSn B7 UDM D3



eMMC Place R134 C179 Close To MPU.

## Defaut Output:1.2V

## Defaut Output:1.1V


VOUT1 5 VLX1 7 VOUT2 9 VLX2 11 VOUT3 31 VLX3 29 VOUT4 27 VLX4 25 BSTOUT 34 VBUSOTG 35 SWOUT 38 VREF 16

# I2C4_SCL DAC1_OUT2

# OTG_FS_ID QSPI_CLK


Layout Note:
The RGMII signals must be length-matched
by RX,TX and MDC groups
ETH_GTX_CLK [2] ETH_TXD0 [2] ETH_TXD1 [2] ETH_TXD2 [2] ETH_TXD3 [2] ETH_RX_CLK [2] ETH_RXD0 [2] ETH_RXD1 [2] ETH_RXD2 [2] ETH_RXD3 [2] ETH_MDC [2] ETH_MDIO [2] ETH_NRST [2] ETH_MDINT [2] ETH_CLK125 [2] ETH_CLK [2] ETH_TX_EN [2] ETH_RX_DV [2]

Layout Note: The SDMMC1 signals must be length-matched

The DCMI signals must be length-matched

The SDMMC3 signals must be length-matched Layout Note:

Layout Note:Wire according to the differential signalUART4_TX

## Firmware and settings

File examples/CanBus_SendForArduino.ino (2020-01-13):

// demo: CAN-BUS Shield, send data
// loovee@seeed.cc

#include <mcp_can.h>
#include <SPI.h>
#include "Seeed_SHT35.h"

/*SAMD core*/
#ifdef ARDUINO_SAMD_VARIANT_COMPLIANCE
  #define SERIAL SerialUSB
#else
  #define SERIAL Serial
#endif

// the cs pin of the version after v1.1 is default to D9
// v0.9b and v1.0 is default D10
const int SPI_CS_PIN = 9;
/*SAMD core*/
#ifdef ARDUINO_SAMD_VARIANT_COMPLIANCE
  #define SDAPIN  20
  #define SCLPIN  21
  #define RSTPIN  7
#else
  #define SDAPIN  A4
  #define SCLPIN  A5
  #define RSTPIN  2
#endif

MCP_CAN CAN(SPI_CS_PIN);                                    // Set CS pin
SHT35 sensor(SCLPIN);

void setup()
{
    SERIAL.begin(115200);

    while (CAN_OK != CAN.begin(CAN_500KBPS))              // init can bus : baudrate = 500k
    {
        SERIAL.println("CAN BUS Shield init fail");
        SERIAL.println(" Init CAN BUS Shield again");
        delay(100);
    }
    SERIAL.println("CAN BUS Shield init ok!");
    
    if(sensor.init())
    {
      SERIAL.println("sensor init failed!!!");
    }
    
}

unsigned char stmp[8] = {0, 0, 0, 0, 0, 0, 0, 0};
void loop()
{
   
    float temp,hum;
    int light = analogRead(A0);
    light = light/(1024.0) * 100.0;
    if(NO_ERROR!=sensor.read_meas_data_single_shot(HIGH_REP_WITH_STRCH,&temp,&hum))
    {
      SERIAL.println("read temp failed!!");
      SERIAL.println("   ");
      SERIAL.println("   ");
      SERIAL.println("   ");
    }
    else
    {
      // send data:  id = 0x00, standrad frame, data len = 8, stmp: data buf
      
      stmp[7] = (u8)temp;
      stmp[6] = 0;
      stmp[5] = (u8)hum;
      stmp[4] = 0;
      stmp[3] = (u8)light;
      stmp[2] = 0;    
      stmp[1] = random(30);
      stmp[0] = 0;    
      CAN.sendMsgBuf(0x00, 0, 8, stmp);
      
      SERIAL.println("read data :");
      SERIAL.print("temperature = ");
      SERIAL.print(temp);
      SERIAL.println(" ℃ ");

      SERIAL.print("humidity = ");
      SERIAL.print(hum);
      SERIAL.println(" % ");
      
      SERIAL.print("light = ");
      SERIAL.print(light);
      SERIAL.println(" % ");
      
      SERIAL.println("   ");
      SERIAL.println("   ");
      SERIAL.println("   ");
    }
    
    delay(100);                       // send data per 100ms
}

// END FILE

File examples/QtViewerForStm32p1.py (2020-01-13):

# -*- coding: utf-8 -*-
"""
This example demonstrates many of the 2D plotting capabilities
in pyqtgraph. All of the plots may be panned/scaled by dragging with 
the left/right mouse buttons. Right click on any plot to show a context menu.
"""

# import initExample ## Add path to library (just for examples; you do not need this)


from pyqtgraph.Qt import QtGui
from PyQt5 import QtWidgets, uic,QtGui
import numpy as np
import pyqtgraph as pg
from PyQt5.QtCore import QTimer
import sys  # We need sys so that we can pass argv to QApplication
import can

app = QtGui.QApplication([])
win = pg.GraphicsLayoutWidget(show=True, title="Basic plotting examples")

Temperature = [0]*100
Humidity = [0]*100
Light = [0]*100

class MainWindow(QtWidgets.QMainWindow):
   
    def __init__(self,*args, **kwargs):
        super().__init__(*args, **kwargs)
        win.resize(480,810)
        pg.setConfigOptions(antialias=True)
        self.p1 = win.addPlot(title="Temp(°C)")
        self.curve1 = self.p1.plot(pen=(0,0,255))
        self.p1.showAxis('bottom', False)
        self.p1.setYRange(10,50)
        win.nextRow()
        pg.setConfigOptions(antialias=True)
        self.p2 = win.addPlot(title="Humi(%)")
        self.curve2 = self.p2.plot(pen=(0,255,0))
        self.p2.showAxis('bottom', False)
        self.p2.setYRange(40,90)
        win.nextRow()
        pg.setConfigOptions(antialias=True)
        self.p3 = win.addPlot(title="Light(%)")
        self.curve3 = self.p3.plot(pen=(255,255,0))
        self.p3.showAxis('bottom', False)
        self.p3.setYRange(0,70)        
        
        self.Timer_Init(Time_Ms = 40)
        self.Can_Init()
        
    def Can_Init(self):     
        can_interface = 'can0'
        bustype = 'socketcan_native'
        self.bus = can.interface.Bus(can_interface, bustype=bustype)
        
    def update(self):
        message = self.bus.recv(1.0) # Timeout in seconds.
        print(message)
        if message is None:
            print('Timeout occurred, no message.')
        Temperature.remove(Temperature[0])
        Temperature.append(message.data[7]+message.data[6]*100)
        Humidity.remove(Humidity[0])
        Humidity.append(message.data[5]+message.data[4]*100)  
        Light.remove(Light[0])
        Light.append(message.data[3]+message.data[2]*100)   
        self.curve3.setData(Light)
        self.p3.enableAutoRange('y', False)           
        self.curve2.setData(Humidity)
        self.p2.enableAutoRange('y', False)        
        self.curve1.setData(Temperature)
        self.p1.enableAutoRange('y', False)            

        # self.p2.graphWidget.clear()
        # self.p2 = win.addPlot(title="Humi(%)", pen=(0,255,0),y=Humidity)
        # p1.graphWidget.clear()
        # p1 = win.addPlot(title="Temp(°C)", pen=(0,0,255),y=Temperature) 
    def Timer_Init(self,Time_Ms):
        timer = QTimer(self)
        timer.timeout.connect(self.update)
        timer.start(Time_Ms)
    # def Data_Init(self):
        # sizeTemperature
        
        # Temperature.remove(Temperature[0])
        # Temperature.append(message.data[7]+message.data[6]*100)
        # Humidity.remove(Humidity[0])
        # Humidity.append(message.data[5]+message.data[4]*100) 
        
## Start Qt event loop unless running in interactive mode or using pyside.
if __name__ == '__main__':
    app = QtWidgets.QApplication(sys.argv)
    main = MainWindow()
    sys.exit(app.exec_())

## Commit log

2020-01-08 modify Specification of stm32
2020-01-14 added demo of canbus
2020-02-05 added dimension of Seeed-Npi-STM32MP157C
2020-02-25 added 3dfile in resourses
    [st.skp]
